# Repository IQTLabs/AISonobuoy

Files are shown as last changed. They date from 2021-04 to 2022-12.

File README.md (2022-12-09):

# AISonobuoy

Maritime Situational Awareness: An Exploration

# About

The AI Sonobuoy project is intended to demonstrate the process and design methodology for developing an AI-enabled hydrophone. We are building an integrated system that detects ship propellers using hydrophones. Data is collected, stored, and processed locally using onboard microprocessors. Onboard detection algorithms trigger remote alerts when objects of interest are detected.

# The Life Cycle of AI at the Edge Systems

## Sensor to Solution

Our Sensor to Solution methodology for this project involves a Collection system to record hydrophone audio, AIS data, and other environmental telemetry. An Analysis process automatically labels the audio data and trains a machine learning (ML) model. The ML model is then deployed on a low-power Detection device which can trigger remote alerts for detection events.

```mermaid 
graph LR
    A(Collection) --> B(Analysis) --> C(Detection)
```

Reference implementations for each of the Sensor to Solution functions can be seen below.

## Collection

### PiBuoy

A buoy designed to run an Raspberry Pi with power management that can do continuous collection of hydrophone audio. It is equipped with an AIS receiver and other sensors such as GPS, LTE, temperature, and a 9-axis gyroscope.

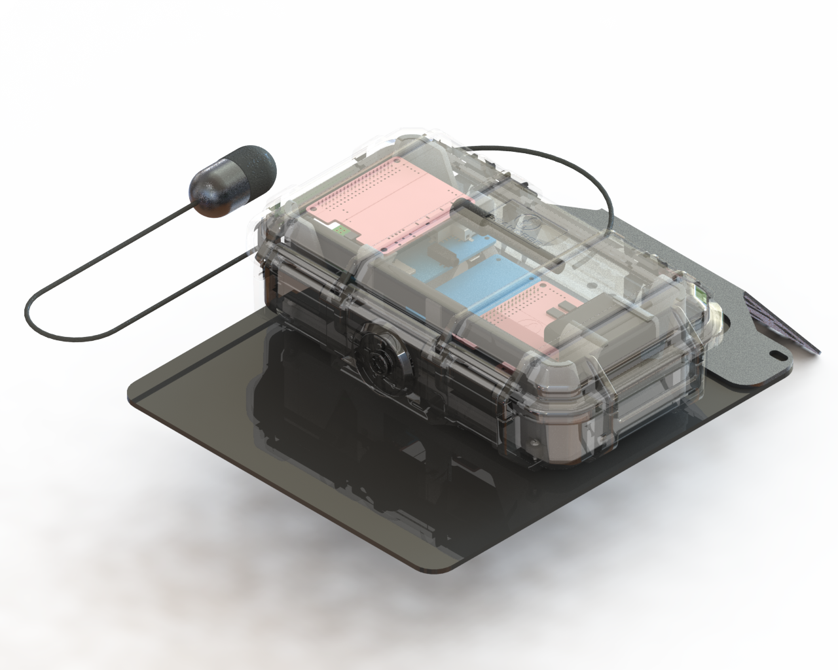
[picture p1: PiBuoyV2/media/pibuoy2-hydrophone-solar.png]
pibuoy


See [https://github.com/IQTLabs/aisonobuoy-collector-raspberrypi](https://github.com/IQTLabs/aisonobuoy-collector-raspberrypi)

## Analysis

### Manual Labeling

The simplest method for getting started with analysis is to manually label the audio data.  We use [Audacity](https://www.audacityteam.org) to label segments of boat/no\_boat in our audio files.

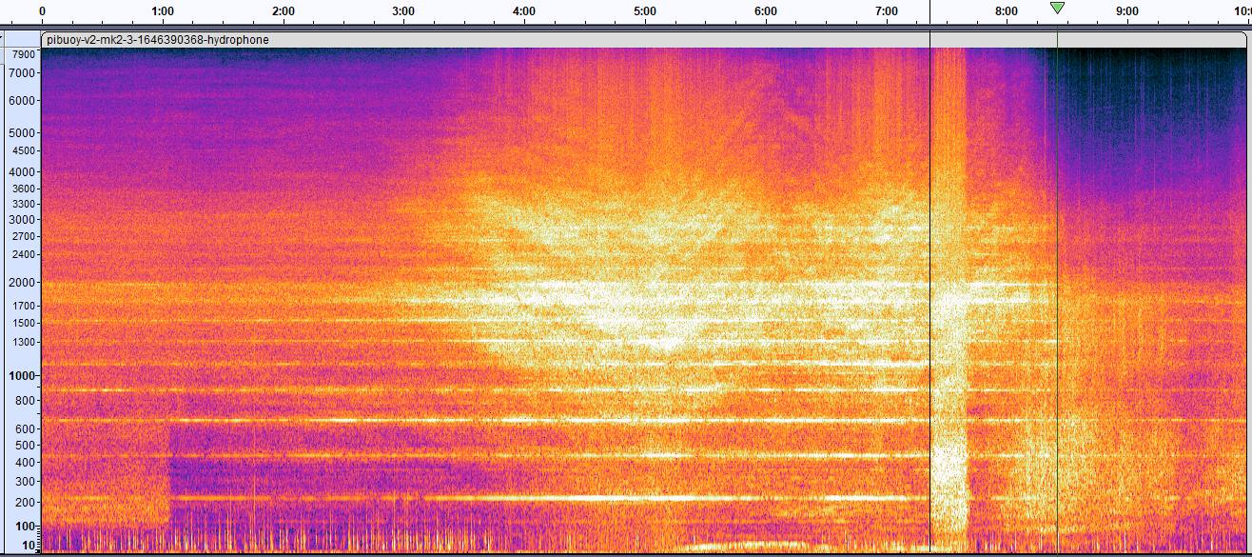
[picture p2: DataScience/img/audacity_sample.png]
pibuoy audacity


### Edge Impulse

With a set of labels in hand, we create a machine learning model using [Edge Impulse](https://www.edgeimpulse.com) that can easily be deployed to the edge.  We use spectrogram features to build a binary classifier for boat/no\_boat:

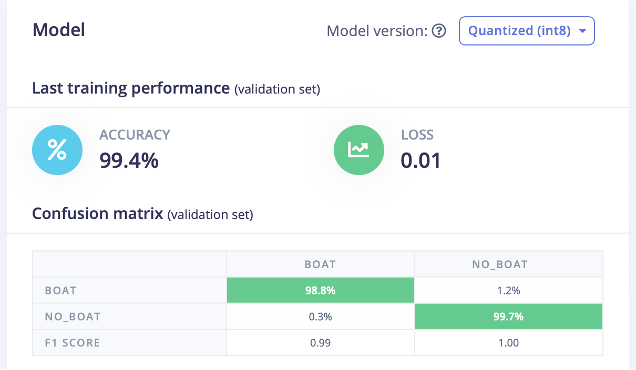
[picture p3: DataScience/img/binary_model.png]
pibuoy ei_model


### Bootstrapping Labels

For more sophisticated models, bootstrapping labels from the data collect is preferable to manual labeling.  We can use GPS tracks or [AIS](https://en.wikipedia.org/wiki/Automatic_identification_system) data to determine vessel speed and distance from the hydrophone.  This allows use to build a 5-class audio classifier with classes: no\_boat, near\_slow, near\_fast, far\_slow, far\_fast. Below we show the far\_slow portion of a particular test run.

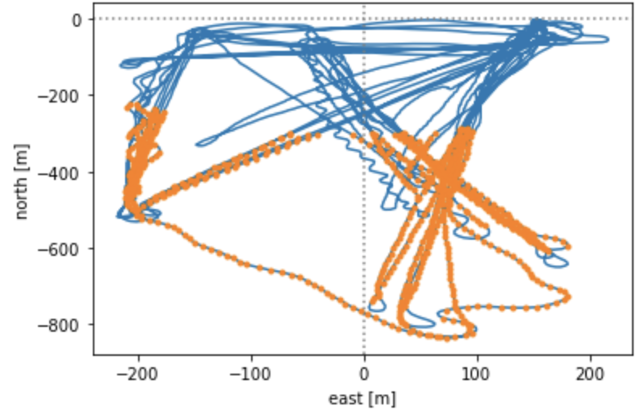
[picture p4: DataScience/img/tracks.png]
pibuoy tracks


Below we show the results of a 5-class Edge Impulse model.

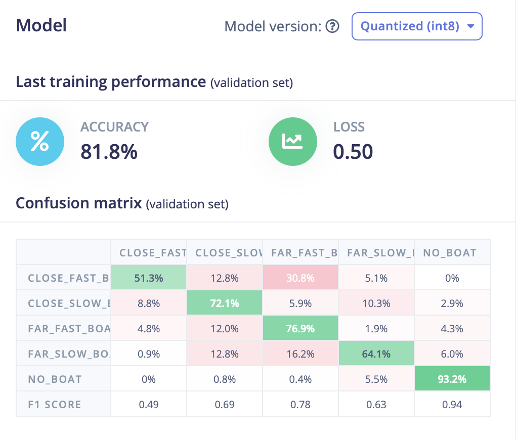
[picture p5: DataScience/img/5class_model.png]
pibuoy ei_model


See [DataScience](./DataScience/README.md) for further details.

## Detection

### ParticleTrackerBuoy

A buoy built around the [Particle.io Tracker SOM Evaluation Board](https://docs.particle.io/datasheets/asset-tracking/tracker-som-eval-board/). The Tracker Eval board is connected to a [Adafruit Quad 2x2 FeatherWing](https://www.adafruit.com/product/4253) via the i2c port to allow Feather form factor devices and sensors to be connected. An optional [Myriota Module](https://myriota.com/) can be used to enable satellite communications. The electronics are housed in a 4in schedule 40 PVC pipe. Ballast is added to the bottom of the pipe for appropriate floatation orientation. 

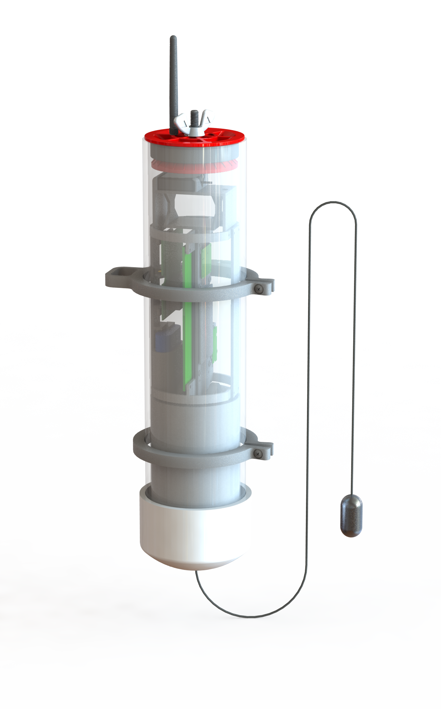
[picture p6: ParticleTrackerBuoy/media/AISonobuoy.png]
particle-tracker-buoy


See [ParticleTrackerBuoy/README](ParticleTrackerBuoy/README.md)

# Data Visualization

[Dashboards](https://alper.datav.is/assets/publications/dashboards/dashboards-preprint.pdf) and data visualizations are a key component of modern sensor collection systems, providing greater data visibility, transparency, and a common operating picture.

As part of the AI Sonobuoy project, we are developing a series of visualizations (shown below with locations masked) to help users with a wide range of real-time monitoring and operational decision-making tasks.

|Cloud IoT Visualizations|React Dashboard (Telemetry Data)|React Dashboard (Map View)|
|:--:|:--:|:--:|
|Thumbnail 1|Thumbnail 2|Thumbnail 3|

This visualization prototyping effort is a work-in-process focused on displaying the AI Sonobuoy's location, temperature (°F), humidity, and state of charge. However, future extensions might visualize different types of data and/or adopt different data encoding strategies. For more details, please see the `aisonobouy-react-dashboards` repository (currently internal-only).

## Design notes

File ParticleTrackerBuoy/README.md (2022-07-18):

# ParticleTrackerBuoy

## About

The Particle Tracker Buoy is an implementation of an Edge AI Detection device. It is intended to demonstrate the concept of an AI Sonobuoy. 



## Hardware

The Particle Tracker Buoy was designed to use low-cost and easily accessible components.

- Particle.io Tracker SOM
- Myriota Dev Kit
- Adafruit nRF52840 Sense MCU
- Adafruit Featherwing Quadrupler
- Adafruit Electret MAX4466 AMP
- Adafruit lithium ion 6600mAh battery
- 4in PVC pipe components
- 3D Printed chassis ([STL Files](stl-files))
- [Aquarian H2A Hydrophone](https://www.aquarianaudio.com/h2a-hydrophone.html)

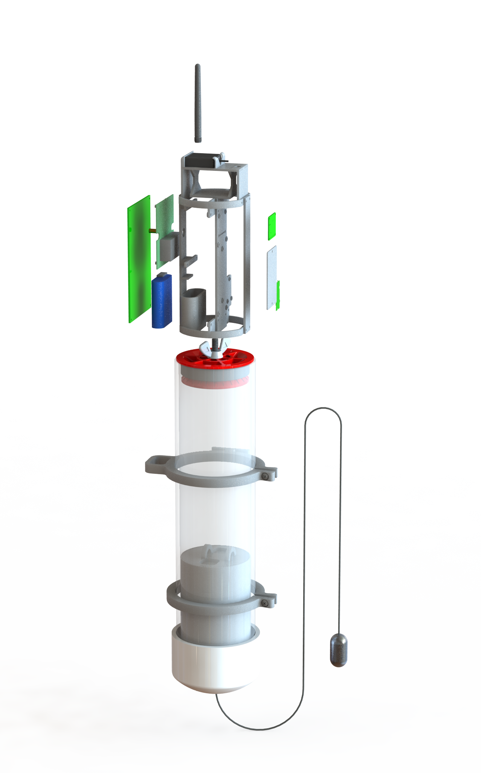
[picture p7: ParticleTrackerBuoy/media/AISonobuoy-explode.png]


[STL Files](stl-files)

## Wiring

```
┌───────────────┐     ┌────────────┐     ┌────────────┐     ┌───────────┐     ┌────────────┐
│   [SATCOM]    │     │[C&C /TELEM]│     │  [ML MCU]  │     │[AUDIO AMP]│     │[HYDROPHONE]│
│               │     │            │     │            │     │           │     │            │
│    Myriota    │     │  Particle  │     │  nRF52840  │     │  MAX4466  │     │  Aquarian  │
│      Dev      │     │  Tracker   │     │   Sense    │     │           │     │    H2A     │
│      Kit      │     │            │     │            │     │           │     │            │
│               │     │            │     │            │     │           │     │            │
│               │     │            │     │            │     │           │     │            │
│   26/LEUART TX├─────┤UART RX     │     │          A0├─────┤VCC        │     │            │
│   28/LEUART RX├─────┤UART TX     │     │          A1├─────┤OUT────────┼─────┤RED         │
│               │     │            │     │            │     │           │     │            │
│               │     │      A0/SDA├───┬─┤A4/SDA      │     │        MIC├─────┤GREEN       │
│               │     │            │   │ │            │     │           │     │            │
│               │     │      A1/SCL├─┬─┼─┤A5/SCL      │     │        GND├─────┤BLACK       │
│               │     │            │ │ │ │            │     │           │     │            │
│               │     │            │ │ │ │            │     │           │     │            │
│ VEXT          │     │            │ 1 1 │            │     │           │     │            │
│ /3.3      GND │     │ 3.3    GND │ 0 0 │ 3.3    GND │     │      GND  │     │            │
└──┬─────────┬──┘     └──┬──────┬──┘ k k └──┬──────┬──┘     └───────┬───┘     └────────────┘
   │         │           │      │    │ │    │      │                │
   │                     │           │ │    │
   └─────────────────────┴───────────┴─┴────┘
```

## Software

- The Particle Tracker firmware and flashing instructions are located in the [aisonobuoy-particle-tracker](https://github.com/IQTLabs/aisonobuoy-particle-tracker/) submodule.

- The Myriota Modem firmware and flashing instructions are located in the [modem-myriota](https://github.com/IQTLabs/modem-myriota) submodule

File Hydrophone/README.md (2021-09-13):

# TinyML & Hydrophones

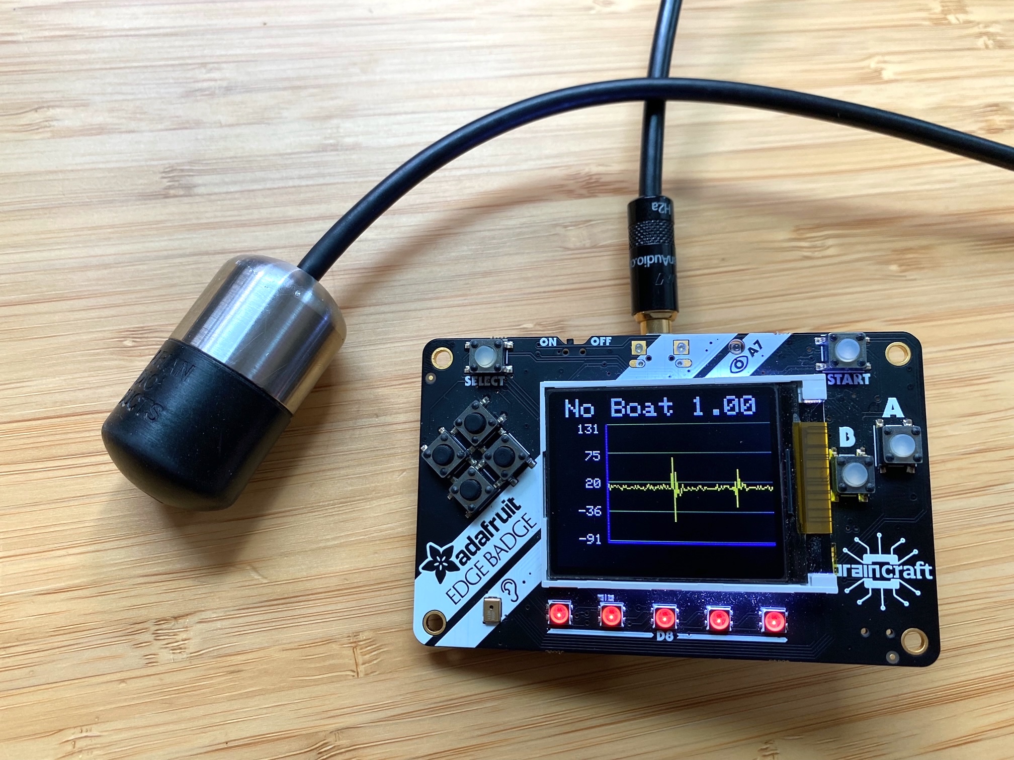
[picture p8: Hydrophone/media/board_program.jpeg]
board


## What are these things?

This is a small effort to look at running ML models against Hydrophone data on an Arduino or similar microcontroller. TinyML focuses on getting machine learning working on these lower power devices. New tools, like [Edge Impulse](https://www.edgeimpulse.com), have made it easy to start building your own ML models. 

Hydrophones are microphones that can capture underwater sounds. You will often see them in movies where they are hunting submarines. There are lots of interesting things you can hear underwater, like fish, volcanos and boats. 

Being able to push audio from a hydrophone through a TinyML model would make it possible to build a self-contained sensor that could detect underwater events.

## What is this?

This work was put together to see if it is possible to detect underwater events on an Arduino. It includes a board for connecting a hydrophone to a microntroller and a small Arduino program that runs an ML model and displays whether a boat was detected.

### Hydrophone Interface Board

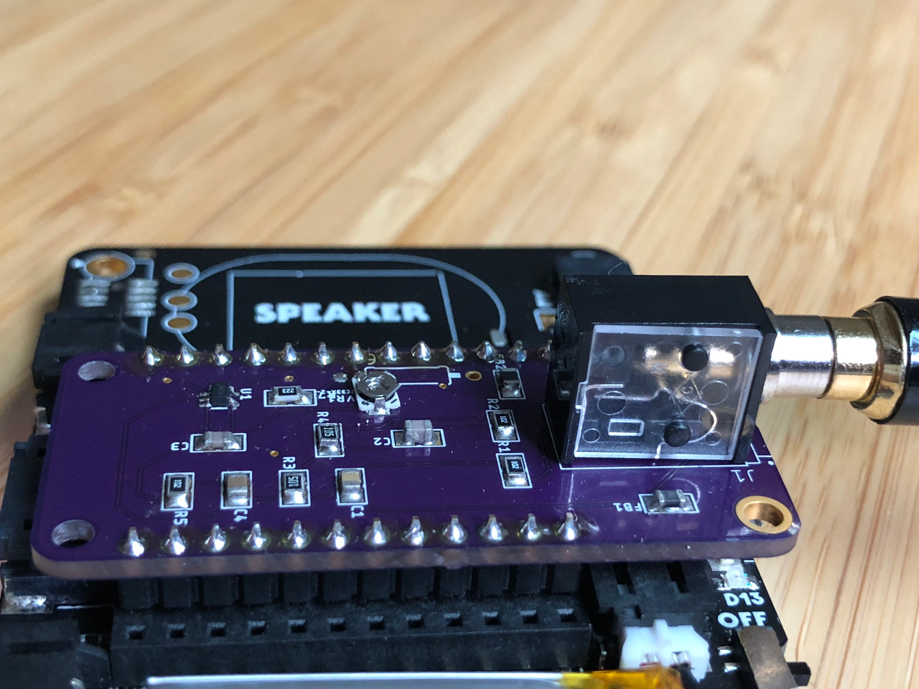
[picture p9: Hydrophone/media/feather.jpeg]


This is a Featherwing form factor board that has a 3.5mm jack, a MAX4466 chip and adjustable gain. It outputs the amplified audio out on one of the Feather analog pinouts. There is a short step-by-step walk through on how I built the board on [Hackster.io](https://www.hackster.io/robotastic/hydrophone-feather-board-03f1d7).

I used the following parts. I am not an EE, so feel free to pick more appropriate components (and send me a PR if you do!):
- [Adafruit PyBadge](https://www.adafruit.com/product/4200)
- [Capacitor 0.01uF / 10000pF 0805](https://www.digikey.com/en/products/detail/CL21C103JBFNNNG/1276-6487-1-ND/5958115?itemSeq=376128529)
- [Capacitor 10uF 0805](https://www.digikey.com/short/m8wb1vc5)
- [Capacitor 100pF 0805](https://www.digikey.com/short/bvph8r4p)
- [Capacitor 0.1uF 0805](https://www.digikey.com/short/ftrt382h)
- [Ferrite Bead 0805](https://www.digikey.com/short/7c5j278m)
- [3.5mm Monojack](https://www.digikey.com/short/59mz8349)
- [Resistor 1k ohm 0805](https://www.digikey.com/short/q990d7bq)
- [Resistor 1M ohm 0805](https://www.digikey.com/short/53rz9h3m)
- [Resistor 22K ohm 0805](https://www.digikey.com/short/hj1djmt8)
- [MAX4466EXK+T  SC-70-5](https://www.digikey.com/short/vnww7j39)
- [Featherwing Male Headers](https://www.adafruit.com/product/3002) 

Here is a short journey on how the board came to be:

I selected the Aquarian hydrophone to work with. The [H2A model](https://www.aquarianaudio.com/h2a-hydrophone.html) seemed to be rugged and reasonably priced, for a hydrophone. It uses a standard 3.5mm jack, making it easy to connect to a lot of different recorders. 

I haven't worked much with microphones before, so I learned a number of things. First, microphones need a bit of power to work, so they will not work on a "line-in" input. For interfacing with an Arduino, this means that you can not simply hook it up to a GPIO pin and read the signal. You need to put some power through the microphone. Secondly, the actual signal from a microphone is quite faints and needs to be amplified before you can start to work with. 

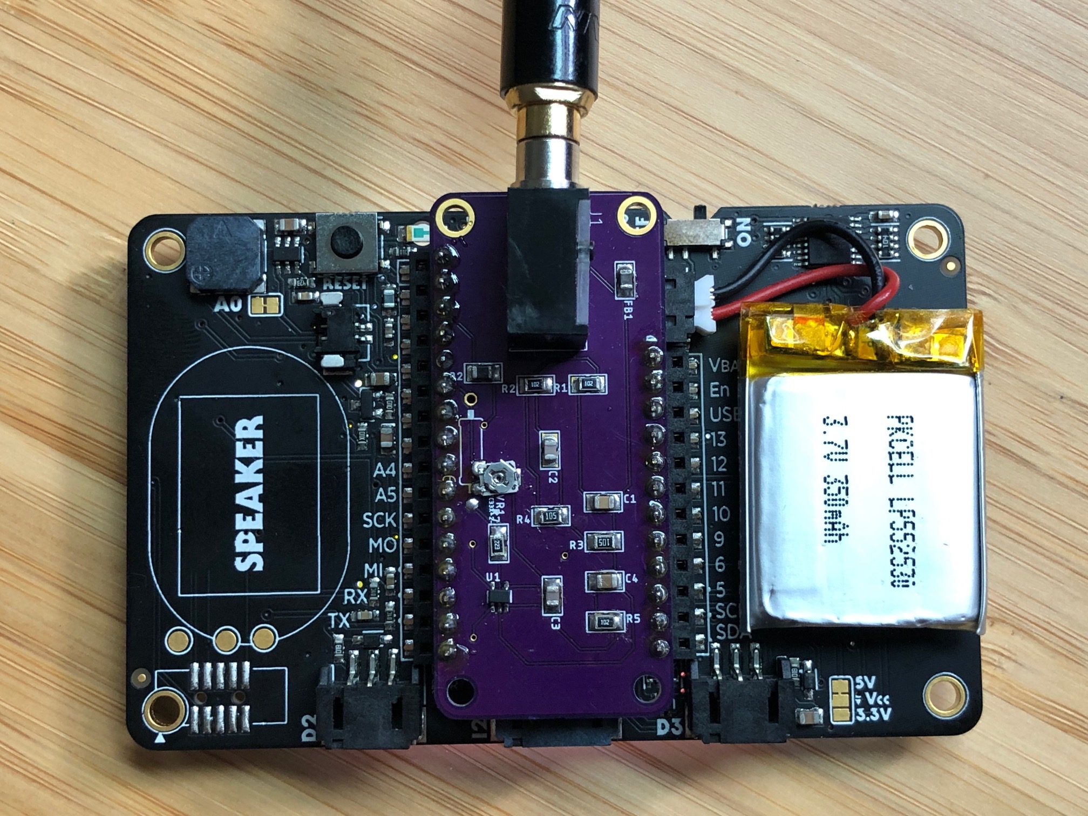
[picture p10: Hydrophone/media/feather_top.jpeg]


The good news is that there are lots of existing chips for working with microphones that handle both the power and the gain. The surprising thing though, was that I couldn't find an existing board that had a 3.5mm jack and was designed to be connected to an Arduino. In fact, there wasn't really that much information about recording analog audio, directly from a microphone using Arduino. Most of the microphone breakout boards I found were for MEMS style microphones and most of them put out a digital signal. 

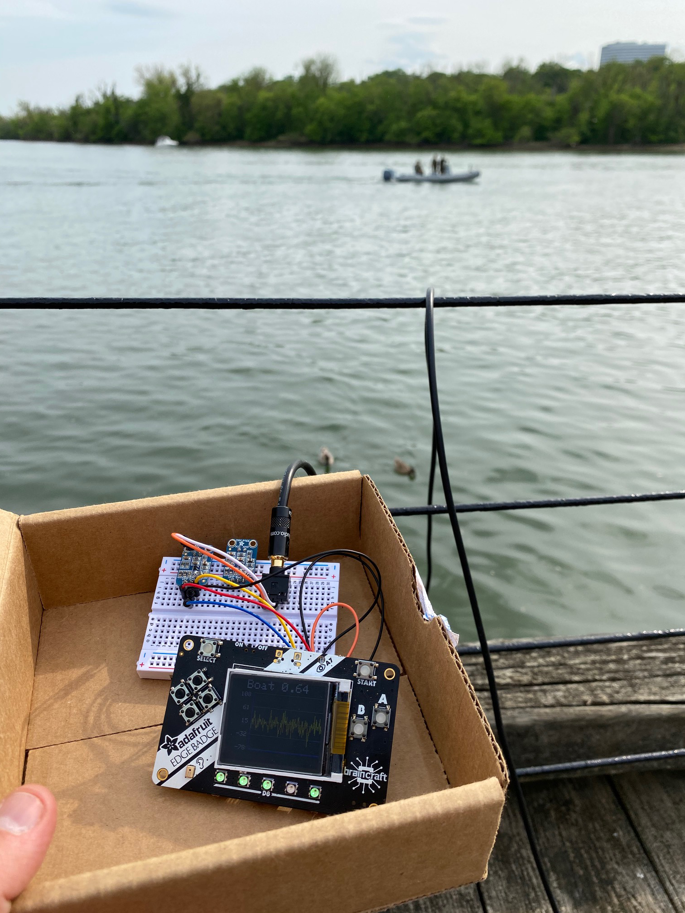
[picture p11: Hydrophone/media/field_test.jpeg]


Adafruit does have a nice [breakout board](https://www.adafruit.com/product/1063) that uses a MAX4466 chip to power and amplify a Electret  Microphone. This is a similar type of microphone as the one inside the hydrophone. Adafruit also published a nice [guide](https://learn.adafruit.com/tensorflow-lite-for-edgebadge-kit-quickstart/assembly) on how to connect this microphone to one of their [dev boards](https://www.adafruit.com/product/4200) and how to run a TinyML model against that audio. Sampling the audio is a bit of a brute force approach - you simply set an interrupt and sample the pin at a set interval. As a quick experiment, I removed the microphone from the breakout board, added a 3.5mm jack and was able to record audio from the hydrophone.

One of the great things about Adafruit is that they open source all of their hardware designs. I started with the design files for the Electret Mic Breakout Board, moved them around to fit inside the feather form factor and added a 3.5mm jack.

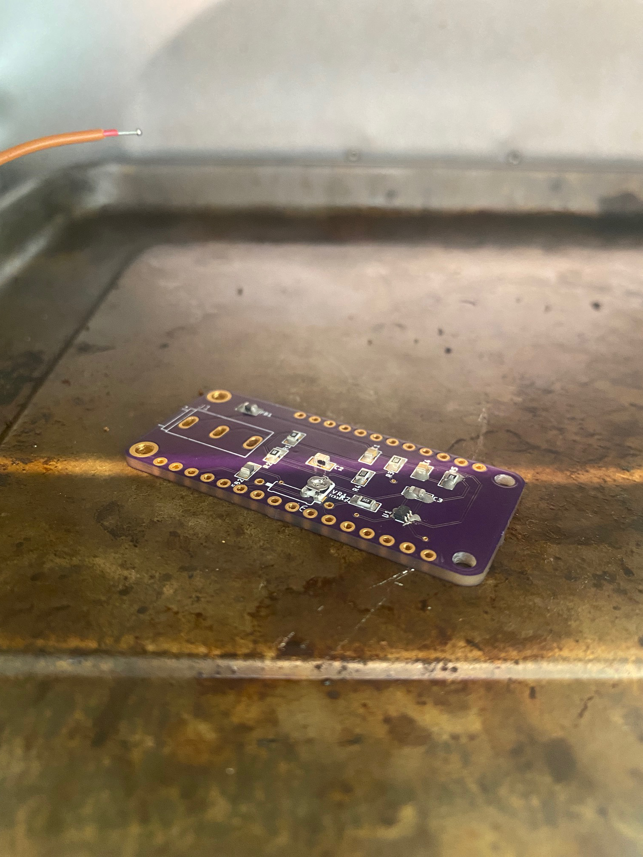
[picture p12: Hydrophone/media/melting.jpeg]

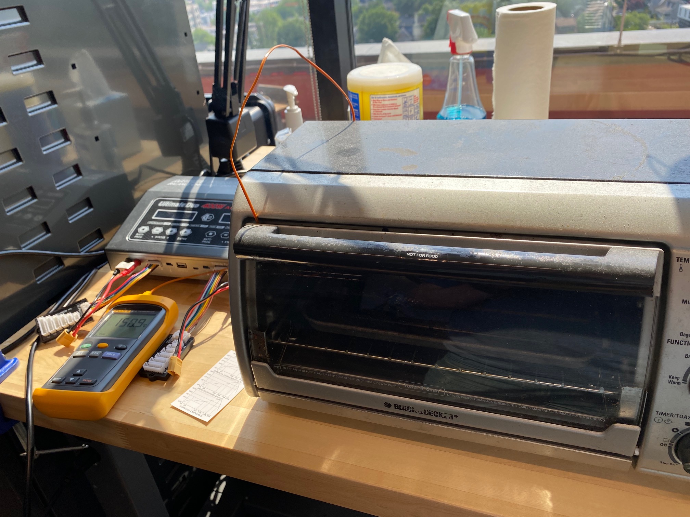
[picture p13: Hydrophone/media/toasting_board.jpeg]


The resulting board fits nicely on the back of the PyBadge and will work with the large range of dev boards that are in the Feather form factor.

Unfortunately, the audio from the interface board is not as high quality as audio recorded from a digital recorder (Zoom H1n). In order to evaluate performance I used an underwater speaker to playback an audio clip. I placed both the microphone and hydrophone in bucket, to try and make it a little more realistic. 

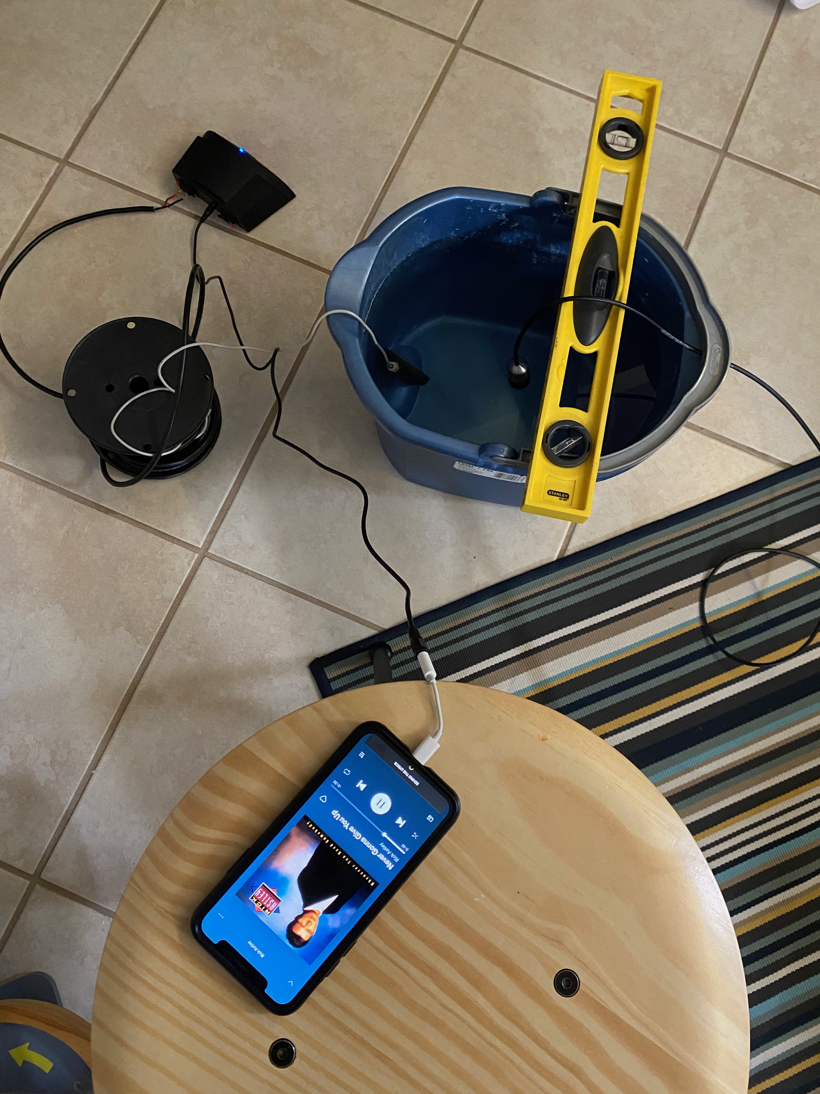
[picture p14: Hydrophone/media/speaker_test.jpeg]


- [Interface Board](media/FeatherWing-Audio-Test.wav)
- [Digital Recorder](media/Digital-Recorder.wav)

As you can hear, the audio recorded by the interface board is a little more muffled and has more noise than the audio recorded by the digital recorder. (It is a little jumpy because it is recorded in 1 second segments.)

The difference maybe from the sampling technique used to capture the audio, it is only 12-bits. It is more likely from the design of the interface board. Cleaning amplifying audio is an art... and I am not an artist. Any improvements to the design of the interface board would be greatly appreciated.

### Arduino Program

The Arduino program builds off of the example Arduino program from Edge Impulse for inferencing. It is designed to run on the Adafruit [Pybadge](https://www.adafruit.com/product/4200) or Edge Badge. These are a series of development boards with a SAMD51 Cortex M4F processor and a small TFT LCD screen. 

The example program is written to pull audio from a PDM microphone. I updated it to instead sample from an analog pin. The results of running the model on the audio are displayed on the screen, along with the waveform of the audio. It makes for a compact kit for debugging and evaluating model performance in the field.

## Building an ML Based Boat Detector

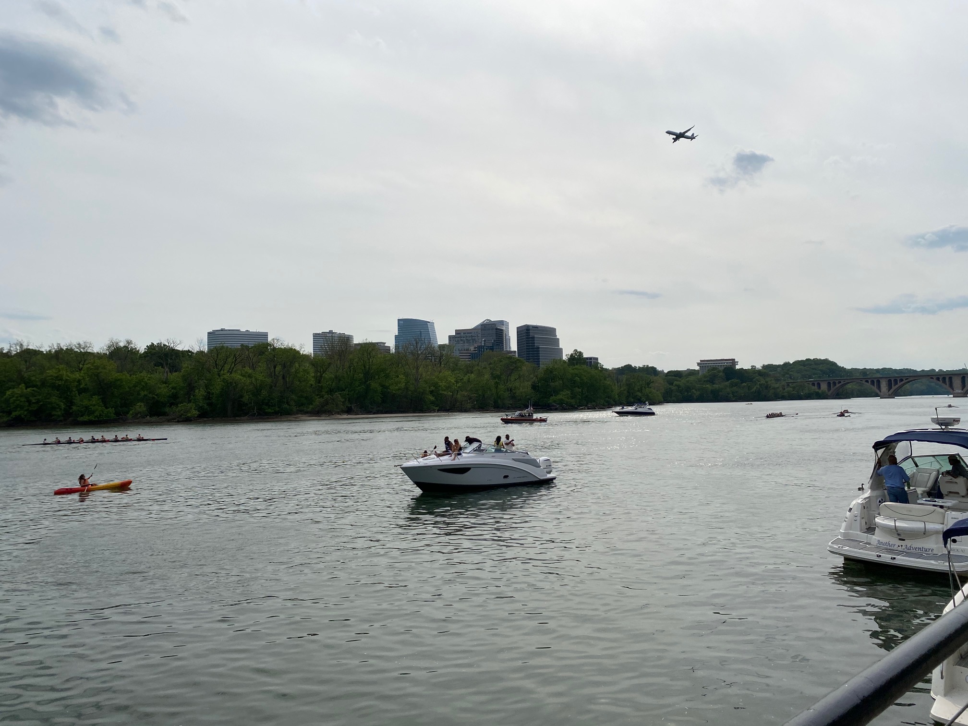
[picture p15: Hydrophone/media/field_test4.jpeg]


Generally, the first step in building an ML model is to collect data and label it. For boat detection, I wanted recordings where there was a boat going by in the water and also recordings where there are no boats present. I captured the recordings using a [Zoom H1n recorder](https://zoomcorp.com/en/us/handheld-recorders/handheld-recorders/h1n-handy-recorder/) and the Acquarian hydrophone. In addition to not being an audio expert, I am also not a boating expert. I learned a couple lessons about boats by trying to make these recordings:

1. Just because a boat is docked and not moving, doesn't mean that it is making boat sounds. It turns out that a pump and maybe a motor will be running even if the boat is docked. This means that it is a bad idea to try and record near a marina, because there will be a lot of background boat sounds, even if nothing is moving nearby.
1. Boats can sound very different. The diesel engine on the water taxi sounds a lot different that the outboard engine on a power boat.

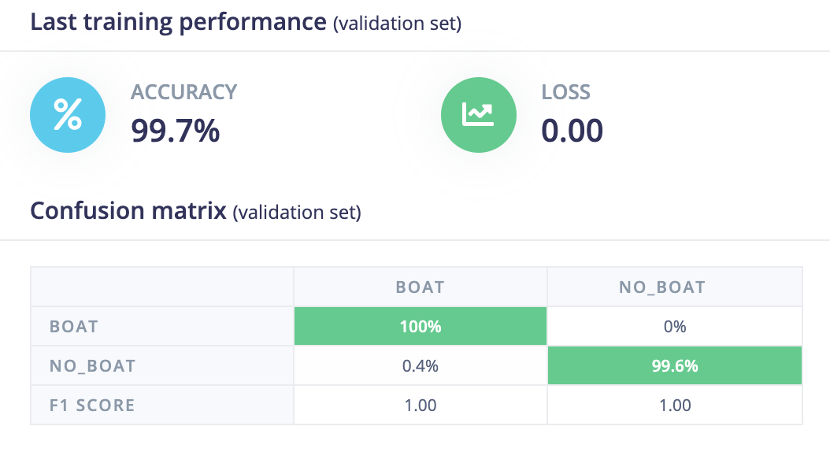
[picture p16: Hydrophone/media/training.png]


I uploaded the different recordings to Edge Impulse and trained a model. They have recently added an AutoML feature to the platform and using that I was able to train a model that almost perfectly classified each type of audio. This is encouraging, but also suggests that I may need more audio and more variety.

## Results 
I did some field evaluation and the system is able to detect nearby boats. More testing is need to see how it would perform in different bodies of water besides a river. Additional training data should help improve performance and allow the model to generalize to a broader range of boats and conditions. Improvements to the interface board should also improve performance.

An Arduino library that includes this model is included. I will look to added the recorded audio to the repo in the future.

## Contact

If you have questions or advice, please reach out to me (Luke Berndt) -> lberndt@iqt.org

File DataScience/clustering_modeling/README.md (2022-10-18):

# Clustering + Plotting Pipeline for Hydrophone Audio Data

This pipeline creates 1-Dimensional audio features and then clusters them via k-Means clustering and plots a dimensionality reduced UMAP with ground truth and prediced class labels. An example can be seen below. 

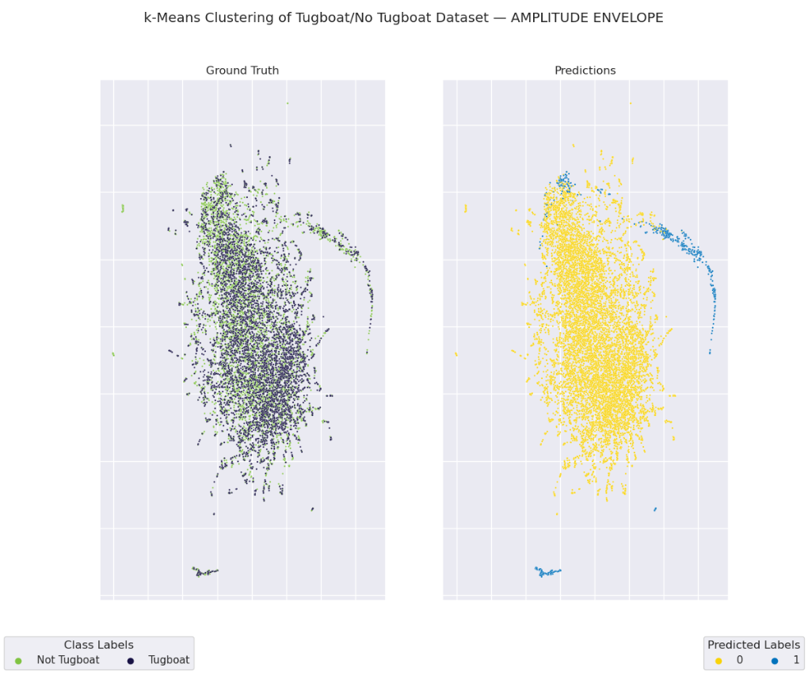
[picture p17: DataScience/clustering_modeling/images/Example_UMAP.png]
UMAP


The overall pipeline can be seen below. 

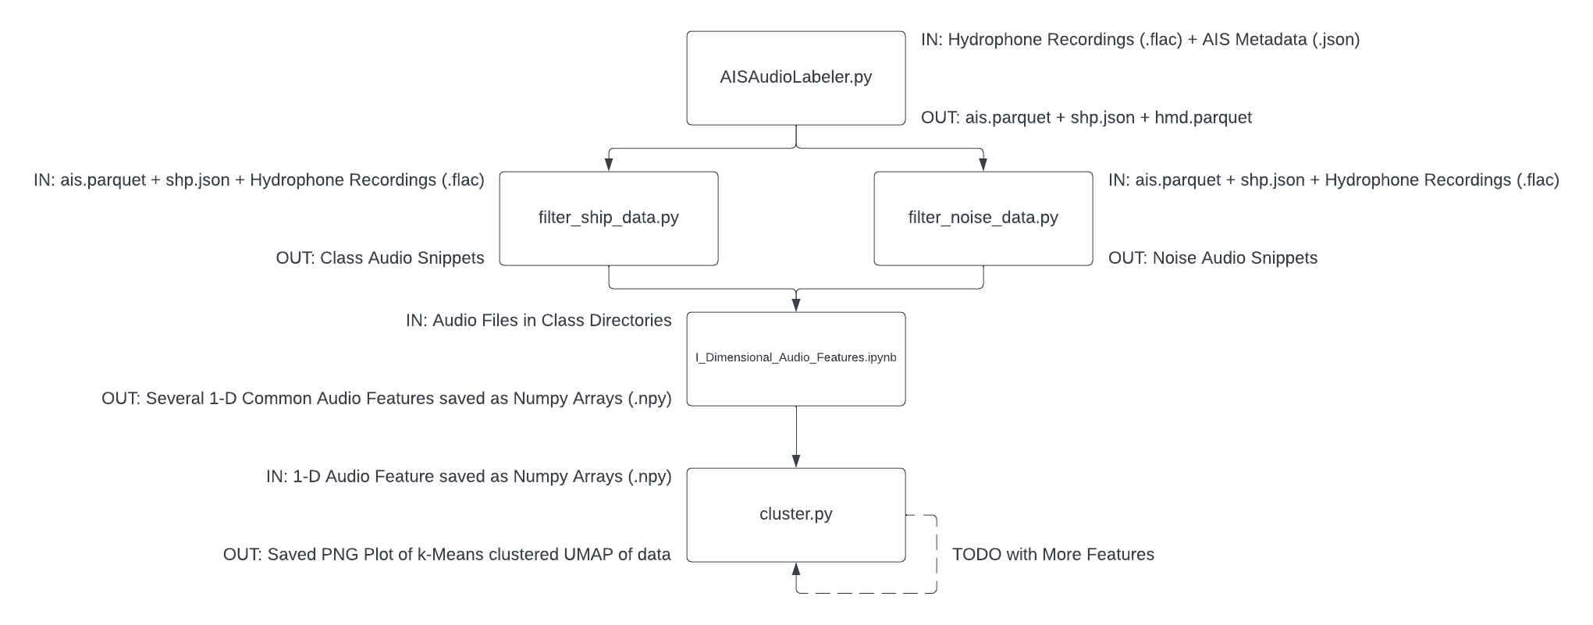
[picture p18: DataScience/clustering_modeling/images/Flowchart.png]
Flowchart


**Note:** This pipeline leverages NVIDIA's `cuML` library as part of their [RAPIDS](https://rapids.ai/index.html) GPU accelerated modeling library, but will still run if you do not have it installed. To run with `cuML`, we reccomend using the Docker option from [here](https://rapids.ai/start.html#get-rapids).

To download (you may have to configure for your enviornment): 

```
docker pull nvcr.io/nvidia/rapidsai/rapidsai-core:22.08-cuda11.5-runtime-ubuntu20.04-py3.8
```

Run the command below from the working directory (`$PWD`) that you want to expose to the docker container where your data is saved (again, you may have to configure for your enviornment).

```
docker run --gpus all --rm -it --shm-size=1g --ulimit memlock=-1 -p 8888:8888 -p 8787:8787 -p 8786:8786 --mount type=bind,source="$(pwd)",target=/rapids/notebooks/host nvcr.io/nvidia/rapidsai/rapidsai-core:22.08-cuda11.5-runtime-ubuntu20.04-py3.8
```

If running on `ssh` in a separate terminal on the host machine you would like to port-forward your `jupyter-lab` session to, run: 

```
ssh -i <PATH_TO_KEYFILE> <HOST_ACCOUNT> -NL 8888:localhost:8888
```

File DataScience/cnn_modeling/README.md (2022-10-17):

# AI SONOBUOY MODELING PIPELINE

**This pipeline is currently under devlopment**

Currently the AISonobuoy Modeling Pipeline takes data collected by the AISonobuoy and trains a ResNet-18 model binary classifier to discriminate between "Tug" boats and everything else. 

The pipeline can be seen below. 

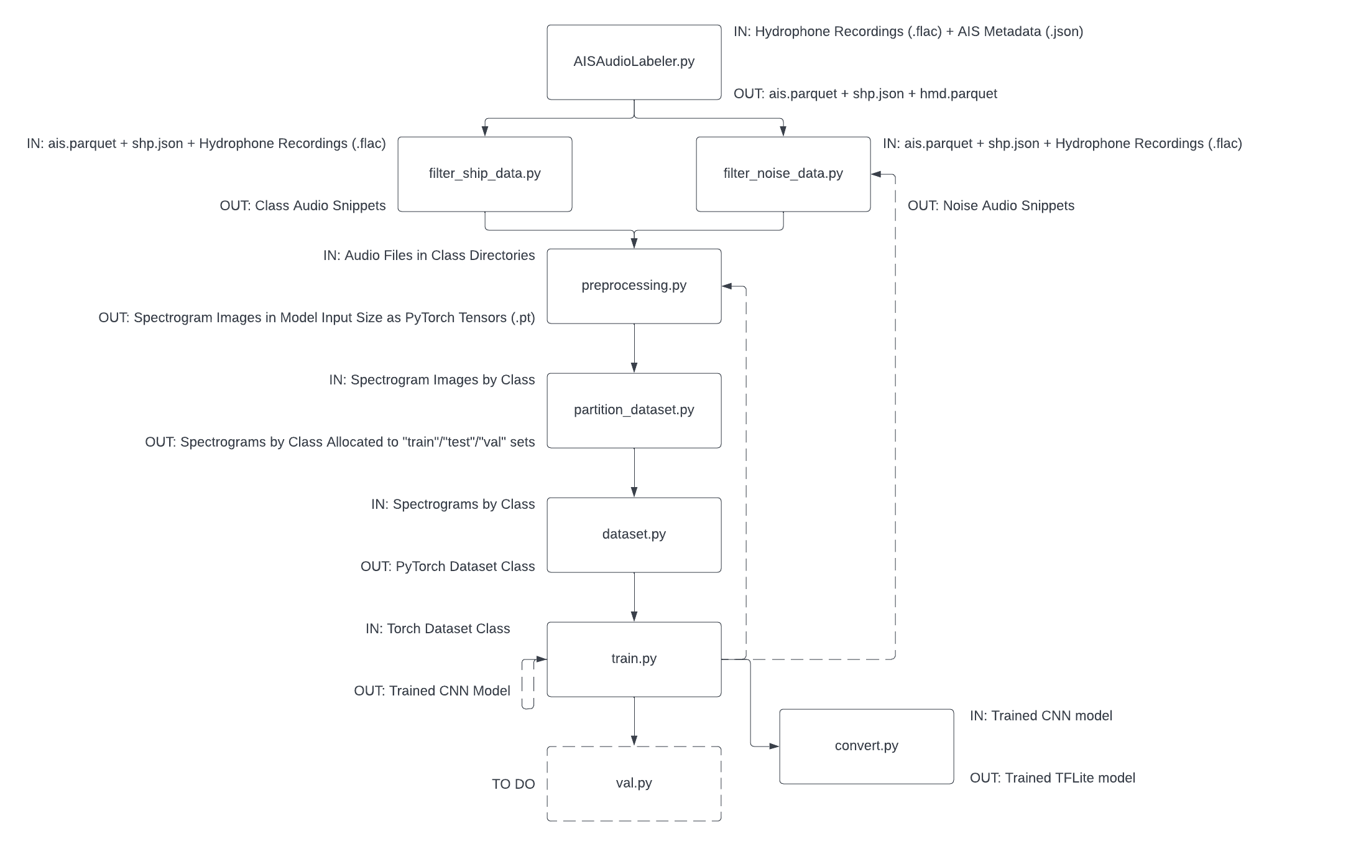
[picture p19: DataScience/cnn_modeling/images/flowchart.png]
flowchart


- `filter_ship_data.py`: Isolates hydrophone audio segments for the class of interest (currently `Tug`) and saves them under a class-label directory 
- `filter_noise_data.py`: Isolates hydrophone audio segments w/ a naive heuristic for filtering out boat noise and saves them under a class-label directory
- `preprocessing.py`: Loads audio segments from the previous step and converts them to an STFT-based spectrogram image PyTorch tensors (of size [3,224,224] which is the ResNet input size) and saves them in class-labelled directories 
- `partition_dataset.py`: Partitions the tensors from the previous step into a `training`, `test`, and `val` sets for training/evaluation and saves as separate set directories w/ class-labelled sub-directories. 
- `dataset.py`: Creates a PyTorch dataset class and creates image-label pairings to be used in training 
- `train.py`: A PyTorch training loop that takes a model (currently ResNet-18) and uses the image-label data pairings to make predictions + learn from them
- `convert.py`: Takes the trained PyTorch model and converts it to an ONNX model, Keras model, and then a TFLite model for use on the edge

---

To visualize model training with Tensorboard run: `tensorboard --logdir=<PATH_TO_TENSORBOARD_LOG_DIR>`. The `logdir` by default is `runs`.

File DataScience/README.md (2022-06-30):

# DataScience

The DataScience directory contains Python modules and Jupyter
Notebooks for creating labeled audio files from simultaneous audio
recordings and GPS or AIS data collections.

The GpxAudioLabeler module provides methods and a command-line
interface for the processing of the audio and GPS data collected in a
controlled environment with specified audio sources. The
AisAudioLabeler module provides methods and a command-line interface
for the processing of the audio and AIS data collected by
pibuoy-v2. The LabelerUtilites module provides methods for coordinate
transformations, clustering, and plotting, and the S3Utilities.py
module provides simplified and documented methods for interacting with
AWS S3.

## GpxAudioLabeler

The GpxAudioLabeler module provides methods and a command-line
interface for:
* Parsing a GPX file produced with a specified structure
* Exporting audio clips by heading, heading first derivative,
  distance, and speed clusters or limits
* Plot source track and label the intersection of the heading, heading
  first derivative, distance, and speed groups

The command line interface has the following usage and optional
arguments:

    Usage: GpxAudioLabeler.py [-h] [-D DATA_HOME] [-c COLLECTION_FILENAME] [-s SAMPLING_FILEPATH] [-C CLIP_HOME]
                              [-p] [-P]

    Optional arguments:
      -h, --help            Show this help message and exit
      -D DATA_HOME, --data-home DATA_HOME
                            The directory containing all GPX, WAV, and JSON files
      -c COLLECTION_FILENAME, --collection-filename COLLECTION_FILENAME
                            The path of the collection JSON file to load
      -s SAMPLING_FILEPATH, --sampling-filepath SAMPLING_FILEPATH
                            The path of the sampling JSON file to process
      -C CLIP_HOME, --clip-home CLIP_HOME
                            The directory containing clip WAV files
      -p, --do-plot-clips   Do plot track with identified clips
      -P, --do-plot-metrics
                            Do plot track with computed metrics

### Collection JSON

The collection JSON contains information in the following format to
describe the sources and hydrophones used during the collection.

Start and stop times are in seconds from the beginning of the
collection. Geodetic latitude, and longitude are in degrees. Elevation
is in meters.

Format:

    {
        "sources": [
            {
                "type": "file" | "bucket"
                "name": "track.gpx",
                "start_t": 0,
                "stop_t": 8000.0
            }
        ],
        "hydrophones": [
            {
                "type": "file",
                "name": "unit.wav",
                "lat": 0.0,
                "lon": 0.0,
                "ele": 0.0,
                "start_t": 1000,
                "stop_t": 9000
            }
        ]
    }

### Sample JSON

The sample JSON document contains entries in the following format
which describe the method, and its parameters, used in creating
labeled samples from the collection. The method can be either
"clusters" or "conditionals".

If "clusters", the samples are all placed in the specified output
directory, and labeled with the start and stop times, and the
distance, heading, heading rate, and speed cluster averages.

If "conditionals", the samples are all placed in the output directory
and labeled with the start and stop times, and the distance, heading,
heading rate, and speed limits. Multiple entries with the
"conditionals" method will result in samples in a set of labeled
directories.

The maximum time delta between positions used to define a contiguous
audio sample is in seconds.

Format:

    [
        {
            "name": "default",
            "method": {
                "type": "clusters",
                "distance_n_clusters": 3,
                "heading_n_clusters": 10,
                "heading_dot_n_clusters": 2,
                "speed_n_clusters": 4
            },
            "delta_t_max": 4.0,
            "n_clips_max": 3,
            "output_dir": "default"
        },
        {
            "name": "close-north-stable-fast",
            "method": {
                "type": "conditionals",
                "distance_limits": [0, 250],
                "heading_limits": [-10, 0, 0, 10],
                "heading_dot_limits": [0, 1],
                "speed_limits": [10, 20]
            },
            "delta_t_max": 4.0,
            "n_clips_max": 3,
            "output_dir": "close-north-stable-fast"
        }
    ]

Where:
* `delta_t_max` specifies the maximum time delta between positions in
  seconds used to define a contiguous audio sample
* `n_clips_max` specifies the maximum number of clips exported in each
  segment

## AisAudioLabeler

The AisAudioLabeler module provides methods and a command-line
interface for:
* Downloading, validating, and decompressing all objects, optionally
  identified by their prefix, in an AWS S3 bucket to a local path
* Loading all AIS files
* Probing all audio files using ffprobe
* Augmenting AIS data with distance from the hydrophone, speed, and
  ship counts when underway, or not underway
* Exporting audio clips from AIS intervals during which a specified
  maximum number of ships at a specified maximum distance are
  reporting their status as underway, and labeling the audio clip
  using the attributes of the ship closest to the hydrophone
* Uploading all audio clips found on the upload path to a bucket with
  a prefix
* Plotting ship status and hydrophone recording intervals
* Plotting histogram of distance for times at which at most a
  specified maximum number of ships are reporting their status as
  underway

The [Automatic Identification System
(AIS)](https://www.navcen.uscg.gov/automatic-identification-system-overview)
is a ship-to-ship collision avoidance system that allows for
communication of position, speed, and other ship data via a VHF
virtual data link (VDL) network. Mariners worldwide use AIS to ensure
safety at sea.

[AIS message reporting
requirements](https://www.navcen.uscg.gov/ais-requirements) depend on
to which of two vessel classes, A and B, a vessel belongs. Class A
vessels meet at least one of the following requirements:
* A self-propelled vessel of 65 feet or more in length, engaged in
  commercial service
* A towing vessel of 26 feet or more in length and more than 600
  horsepower, engaged in commercial service
* A self-propelled vessel that is certificated to carry more than 150
  passengers
* A self-propelled vessel engaged in dredging operations in or near a
  commercial channel or shipping fairway
* A self-propelled vessel engaged in the movement of –
  + Certain dangerous cargo, or
  + Flammable or combustible liquid cargo in bulk

Class B vessels meet at least one of the following requirements:
* Fishing industry vessels
* Vessels certificated to carry less than 150 passengers and that–
  + Do not operate in a Vessel Traffic Service (VTS) or Vessel
  Movement Reporting System (VMRS) area
  + Do not operate at speeds in excess of 14 knots
* Vessels engaged in dredging operations not in or near a commercial
  channel or shipping fairway

AIS messages include [position and static
data](https://www.navcen.uscg.gov/ais-messages) reports. The
AisAudioLabeler module processes Class A position [Message IDs 1, 2,
and 3](https://www.navcen.uscg.gov/ais-class-a-reports) and static
data [Message ID
5](https://www.navcen.uscg.gov/ais-class-a-static-voyage-message-5)
reports, and Class B position and static data [Message ID 18, and
24](https://www.navcen.uscg.gov/ais-class-b-reports) reports.

The command line interface has the following usage and optional
arguments:

    Usage: AisAudioLabeler.py [-h] [-D DATA_HOME] [-c COLLECTION_FILENAME] [-s SAMPLING_FILEPATH] [-C CLIP_HOME]
                              [-d] [--force-download] [--force-ais-parquet] [--force-hmd-parquet] [--force-shp-json]
                              [--export-clips] [--upload-audio-clips] [--plot-intervals] [--plot-histogram]

    Optional arguments:
      -h, --help            Show this help message and exit
      -D DATA_HOME, --data-home DATA_HOME
                            The directory containing all downloaded AIS files
      -c COLLECTION_FILENAME, --collection-filename COLLECTION_FILENAME
                            The path of the collection JSON file to load
      -s SAMPLING_FILEPATH, --sampling-filepath SAMPLING_FILEPATH
                            The path of the sampling JSON file to process
      -C CLIP_HOME, --clip-home CLIP_HOME
                            The directory containing clip WAV files
      -d, --decompress      Decompress downloaded files
      --force-download      Force file download
      --force-ais-parquet   Force AIS parquet creation
      --force-hmd-parquet   Force hydrophone metadata parquet creation
      --force-shp-json      Force SHP JSON creation
      --export-clips        Do export audio clips
      --upload-audio-clips  Do upload audio clips
      --plot-intervals      Do plot ship status and hydrophone recording intervals
      --plot-histogram      Do plot ship distance from hydrophone histogram

### Collection JSON

The collection JSON contains information in the following format to
describe the sources and hydrophones used during the collection.

Geodetic latitude, and longitude are in degrees. Elevation is in
meters.

Format:

    {
        "sources": [
            {
                "type": "bucket",
                "name": "aisonobuoy-pibuoy-v2",
                "prefix": "compressed",
                "label": "v2-mk2-3"
            }
        ],
        "hydrophones": [
            {
                "type": "bucket",
                "name": "aisonobuoy-pibuoy-v2",
                "prefix": "compressed",
                "label": "v2-mk2-3",
                "lat": 0.0,
                "lon": 0.0,
                "ele": 0.0
            }
        ]
    }

### Sample JSON

The sample JSON document contains entries in the following format
which describe the method, and its parameters, used in creating
labeled samples from the collection.

The maximum distance is in meters.

Format:

    [
        {
            "name": "default",
            "max_n_ships": 3,
            "max_distance": 500.0,
            "output_dir": "no-more-than-three-or-500-m-then-min-distance"
        }
    ]

Where:
* `max_n_ships` specifies the maximum number of ships underway
  simultaneously
* `max_distance` specifies the maximum distance of ships underway
  simultaneously from the hydrophone

## LabelerUtilites

The LabelerUtilites module provides methods for:
* Computing the geocentric position given geodetic longitude and
  latitude, and elevation
* Computing geocentric east, north, and zenith unit vectors at a given
  geodetic longitude and latitude, and the corresponding orthogonal
  transformation matrix from geocentric to topocentric coordinates
* Computing the topocentric position and velocity of the source
  relative to the hydrophone, and corresponding heading, heading first
  derivative, distance, and speed
* Computing clusters of distance, heading, heading first derivative,
  and speed
* Plotting source track, and histograms of source distance, heading,
  heading first derivative, and speed

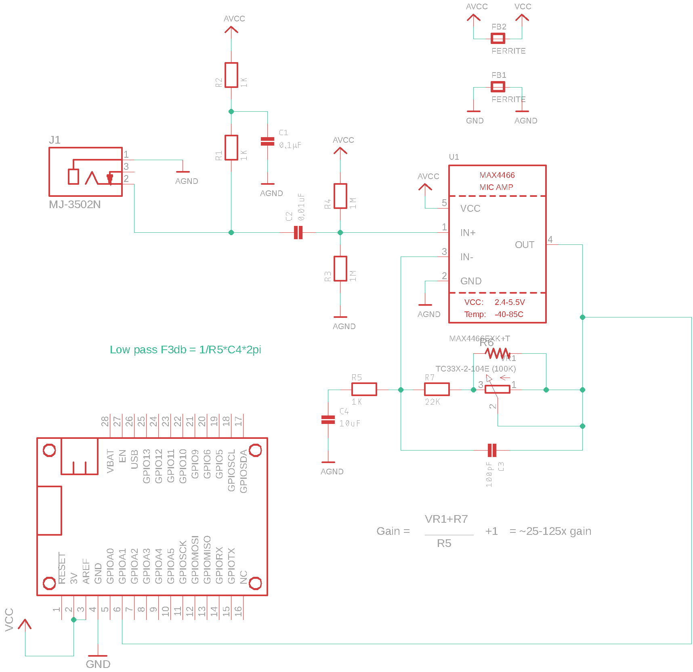
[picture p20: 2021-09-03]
Hydrophone/Featherwing Interface/v1.2 - Fabbed/schematic-v1.2.png

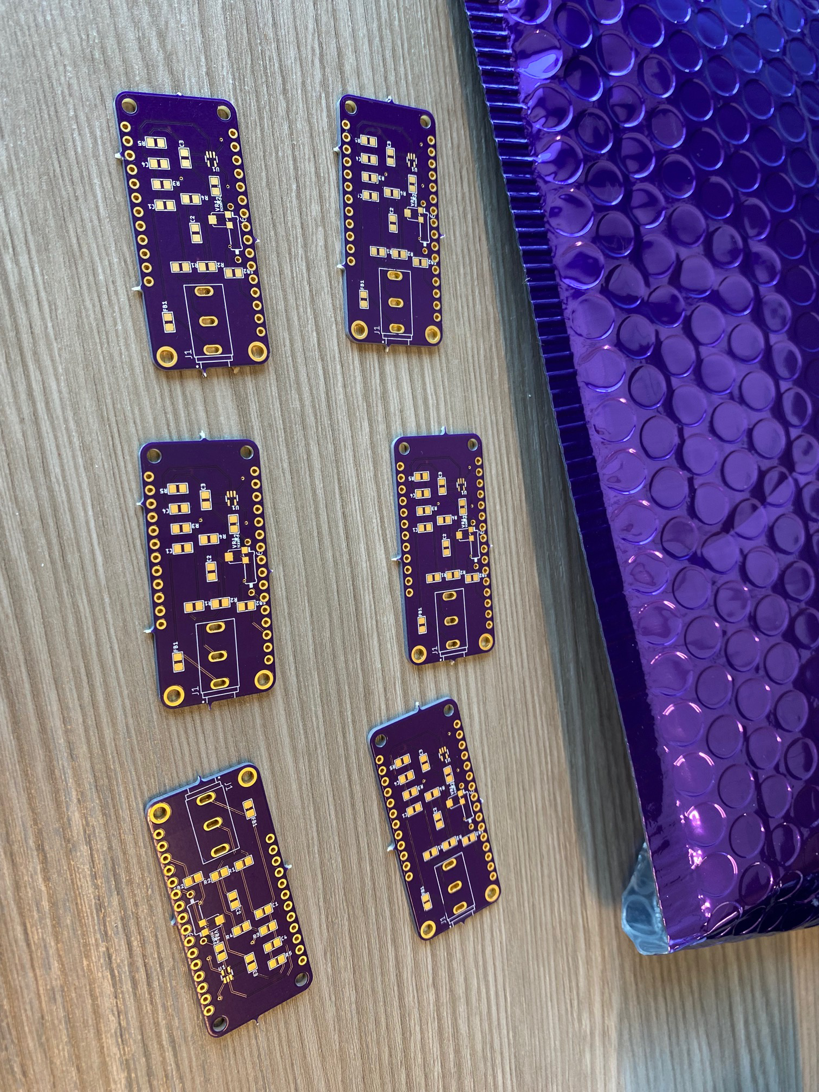
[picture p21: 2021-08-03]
Hydrophone/media/raw_board.jpeg

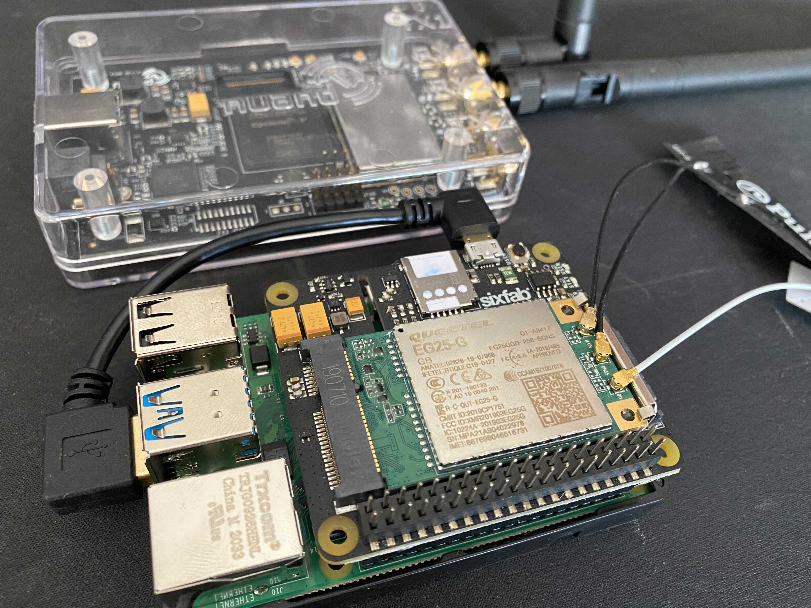
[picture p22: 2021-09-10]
docs/img/sixfab_bladerf.jpg

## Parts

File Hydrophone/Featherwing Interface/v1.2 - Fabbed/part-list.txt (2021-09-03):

Partlist

Exported from featherwing-interface.brd at 9/3/21 9:34 AM

EAGLE Version 9.6.2 Copyright (c) 1988-2020 Autodesk, Inc.

Assembly variant: 

Part     Value               Package                Library      Position (mil)        Orientation

C1       0.1µF               0805                   microbuilder (1350 2100)           R90
C2       0.01uF              0805                   microbuilder (1150 1900)           R0
C3       100pF               0805                   microbuilder (1700 1900)           R0
C4       10uF                0805                   microbuilder (1650 2100)           R90
FB1      FERRITE             0805                   microbuilder (500 2200)            R0
FB2      FERRITE             0805                   microbuilder (850 1650)            R270
J1       MJ-3502N            CUI_MJ-3502N           MJ-3502N     (500 1900)            R0
MS1      FEATHERWING         FEATHERWING            adafruit     (150 1450)            R0
R1       1K                  0805                   microbuilder (900 2050)            R270
R2       1K                  0805                   microbuilder (900 1850)            R270
R3       1M                  0805                   microbuilder (1500 2100)           R270
R4       1M                  0805                   microbuilder (1400 1900)           R270
R5       1K                  0805                   microbuilder (1800 2100)           R90
R6                           0207/10                rcl          (1150 1600)           R180
R7       22K                 0805                   microbuilder (1500 1700)           R180
U1       MAX4466EXK+T        SC70-5                 microbuilder (1700 1700)           R90
VR1      TC33X-2-104E (100K) TRIMPOT_BOURNS_TC33X-2 microbuilder (1250 1700)           R0

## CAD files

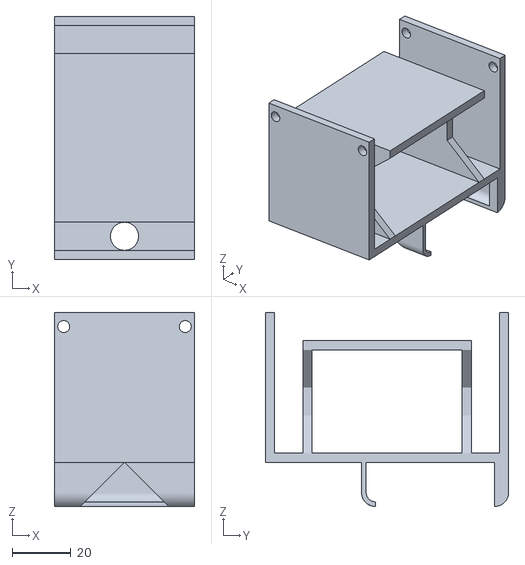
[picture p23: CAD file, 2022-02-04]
ParticleTrackerBuoy/stl-files/4in PVC Particle Tracker Buoy - 3D Printed Electronics Payload Chassis GPS Mount^4in PVC Particle Tracker Buoy-1.STL
47.6 x 82.5 x 65.8

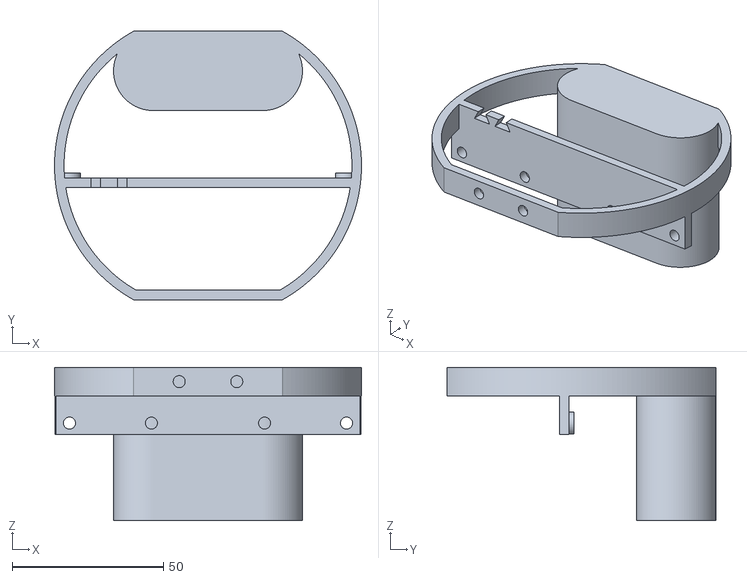
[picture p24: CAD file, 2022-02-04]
ParticleTrackerBuoy/stl-files/4in PVC Particle Tracker Buoy - 3D Printed Electronics Payload Chassis End^4in PVC Particle Tracker Buoy-1.STL
101.6 x 88.9 x 50.8

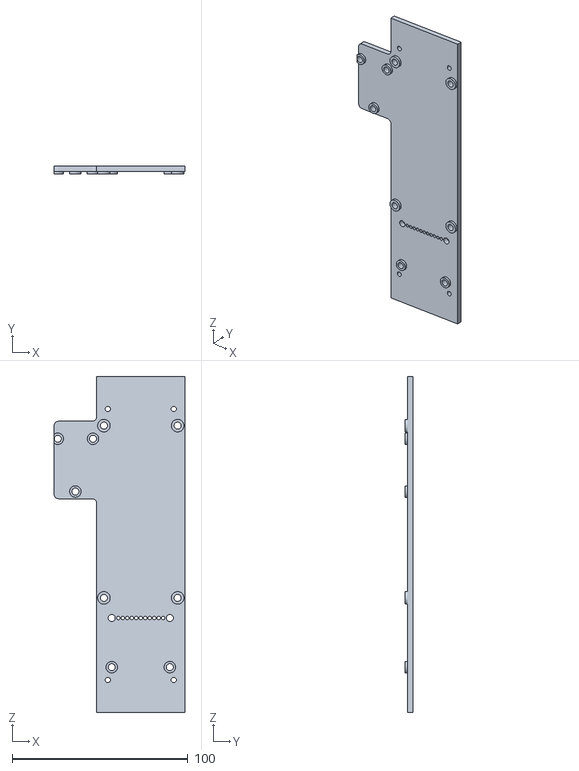
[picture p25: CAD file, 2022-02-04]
ParticleTrackerBuoy/stl-files/4in PVC Particle Tracker Buoy - 3D Printed Electronics Payload Chassis Center Panel^4in PVC Particle Tracker Buoy-1.STL
74.4 x 4.76 x 191.0

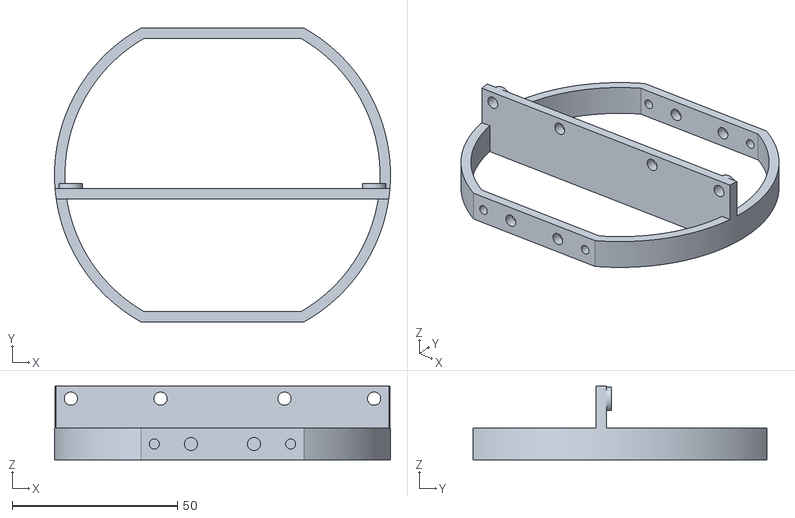
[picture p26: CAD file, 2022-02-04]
ParticleTrackerBuoy/stl-files/4in PVC Particle Tracker Buoy - 3D Printed Electronics Payload Chassis End^4in PVC Particle Tracker Buoy-2.STL
101.6 x 88.9 x 22.2

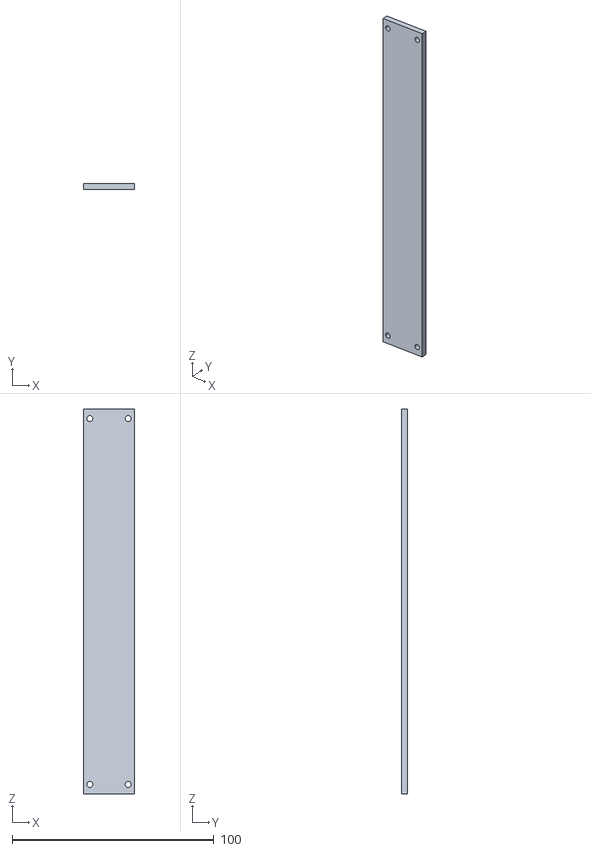
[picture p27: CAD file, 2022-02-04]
ParticleTrackerBuoy/stl-files/4in PVC Particle Tracker Buoy - 3D Printed Electronics Payload Chassis Side Support^4in PVC Particle Tracker Buoy-2.STL
25.4 x 3.17 x 191.0

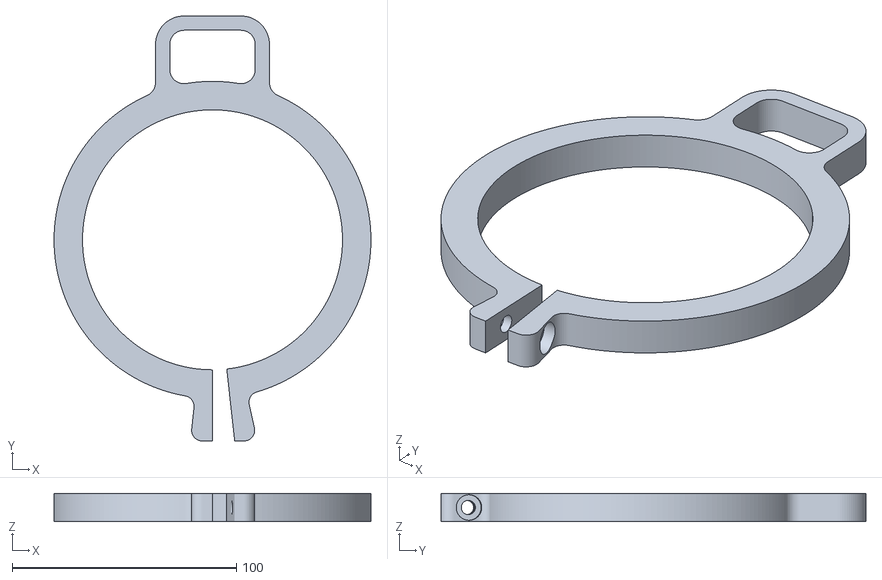
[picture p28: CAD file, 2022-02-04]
ParticleTrackerBuoy/stl-files/4in PVC Particle Tracker Buoy - Tether Strap^4in PVC Particle Tracker Buoy-1 3D Printed Tether Strap-1.STL
141.3 x 189.5 x 12.7

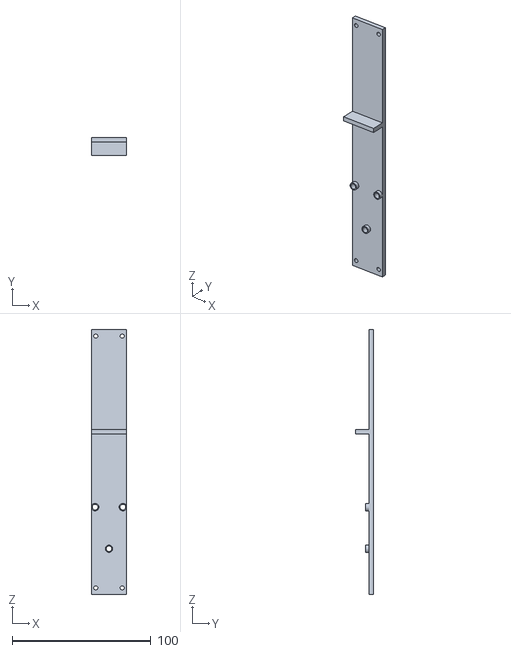
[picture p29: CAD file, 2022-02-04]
ParticleTrackerBuoy/stl-files/4in PVC Particle Tracker Buoy - 3D Printed Electronics Payload Chassis Side Support^4in PVC Particle Tracker Buoy-1.STL
25.4 x 12.7 x 191.0

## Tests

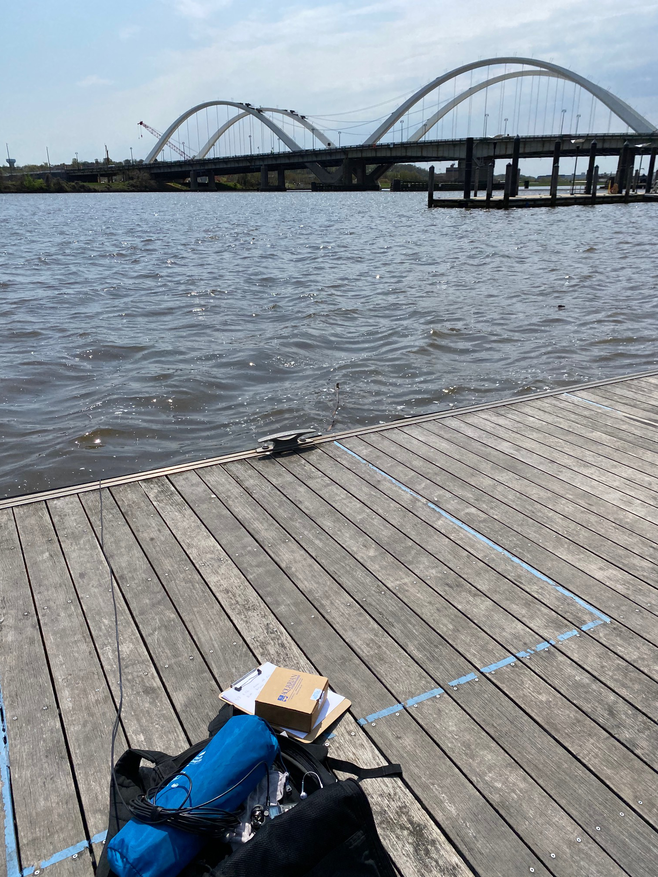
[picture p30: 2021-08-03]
Hydrophone/media/field_test3.jpeg

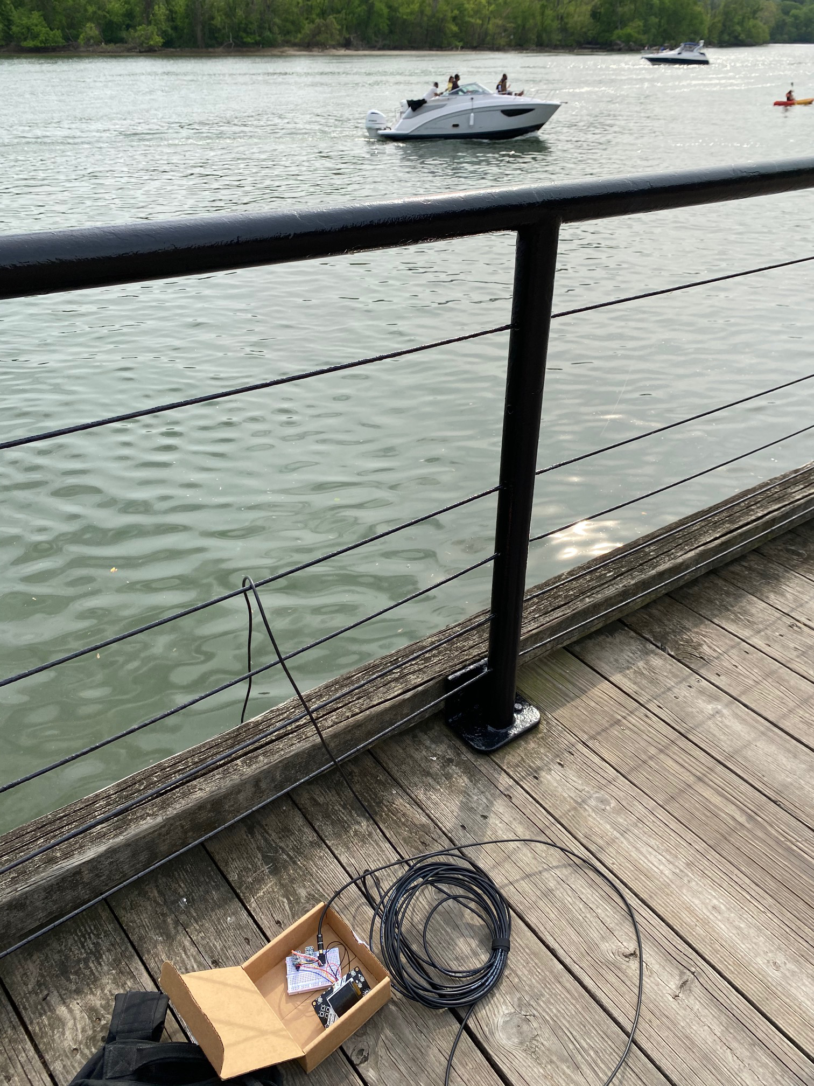
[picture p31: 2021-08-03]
Hydrophone/media/field_test2.jpeg

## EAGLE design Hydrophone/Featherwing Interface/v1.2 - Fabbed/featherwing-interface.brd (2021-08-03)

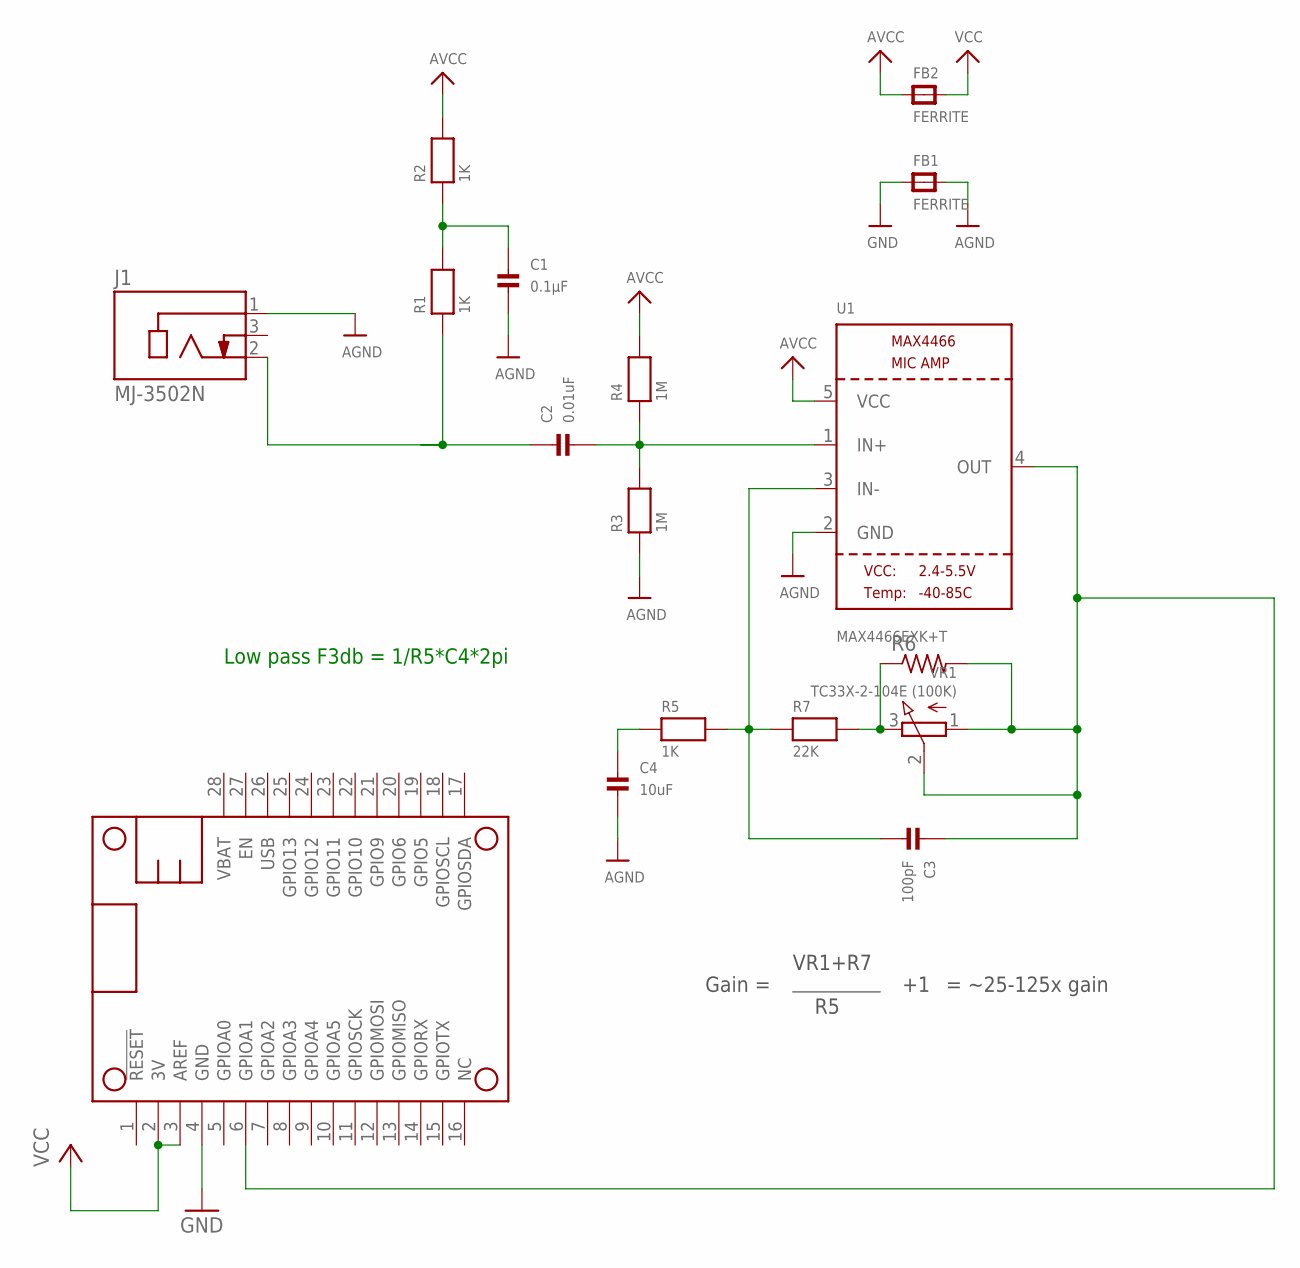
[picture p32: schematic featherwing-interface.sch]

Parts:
C1: 0.1µF; 0805
C2: 0.01uF; 0805
C3: 100pF; 0805
C4: 10uF; 0805
FB1, FB2: FERRITE; 0805
J1: MJ-3502N; CUI_MJ-3502N
MS1: FEATHERWING
R1, R2, R5: 1K; 0805
R3, R4: 1M; 0805
R6: R-US_0207/10; 0207/10
R7: 22K; 0805
U1: MAX4466EXK+T; SC70-5
VR1: TC33X-2-104E (100K); TRIMPOT_BOURNS_TC33X-2

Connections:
AGND: C1.2, C4.2, FB1.2, J1.1, R3.1, U1.2 (GND)
AVCC: FB2.1, R2.2, R4.2, U1.5 (VCC)
GND: FB1.1, MS1.4 (GND)
unnamed: C3.2, R5.2, R7.1, U1.3 (IN-)
unnamed: R6.1, R7.2, VR1.3 (E)
unnamed: C2.1, J1.2, R1.1
unnamed: C1.1, R1.2, R2.1
unnamed: C2.2, R3.2, R4.1, U1.1 (IN+)
unnamed: C3.1, MS1.6 (GPIOA1), R6.2, U1.4 (OUT), VR1.1 (A), VR1.2 (S)
unnamed: C4.1, R5.1
VCC: FB2.2, MS1.2 (3V), MS1.3 (AREF)

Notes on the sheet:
Gain =
VR1+R7
= ~25-125x gain
Low pass F3db = 1/R5*C4*2pi

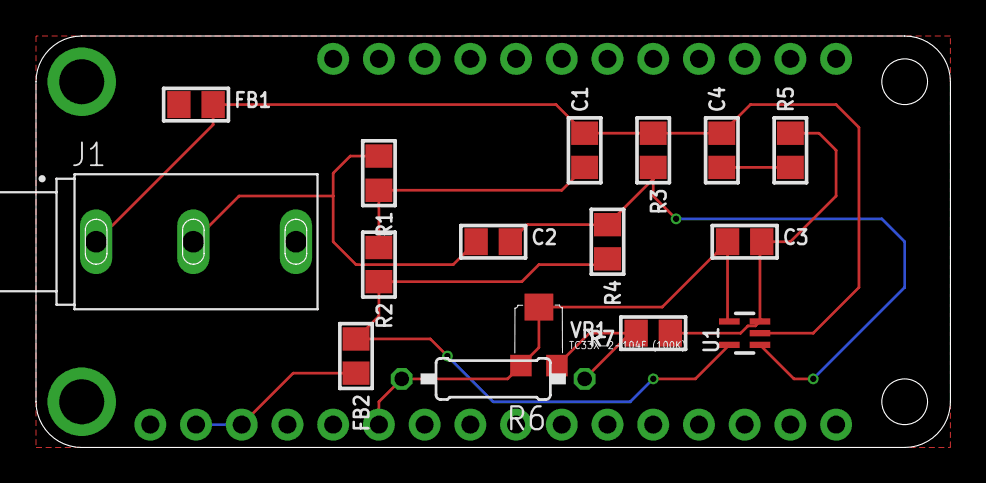
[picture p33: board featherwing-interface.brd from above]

Board: 2 copper layers, 50.8 x 22.9 mm, 17 parts (0 on the bottom side), 11 nets.

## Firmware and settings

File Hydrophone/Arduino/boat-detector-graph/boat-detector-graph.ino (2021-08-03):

/* Edge Impulse Arduino examples
 * Copyright (c) 2021 EdgeImpulse Inc.
 *
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
 * THE SOFTWARE IS PROVIDED "AS IS", WITHOUT WARRANTY OF ANY KIND, EXPRESS OR
 * IMPLIED, INCLUDING BUT NOT LIMITED TO THE WARRANTIES OF MERCHANTABILITY,
 * FITNESS FOR A PARTICULAR PURPOSE AND NONINFRINGEMENT. IN NO EVENT SHALL THE
 * AUTHORS OR COPYRIGHT HOLDERS BE LIABLE FOR ANY CLAIM, DAMAGES OR OTHER
 * LIABILITY, WHETHER IN AN ACTION OF CONTRACT, TORT OR OTHERWISE, ARISING FROM,
 * OUT OF OR IN CONNECTION WITH THE SOFTWARE OR THE USE OR OTHER DEALINGS IN THE
 * SOFTWARE.
 */

// If your target is limited in memory remove this macro to save 10K RAM
#define EIDSP_QUANTIZE_FILTERBANK   0
#define USE_EXTERNAL_MIC A1
//#define AUDIO_OUT A0     
/* Includes ---------------------------------------------------------------- */

#include <boat-detector_inferencing.h>
#include <Adafruit_Arcada.h>
#include <CircularBuffer.h>
#include <Math.h>

// Color definitions
#define BACKGROUND_COLOR __builtin_bswap16(ARCADA_BLACK)
#define BORDER_COLOR __builtin_bswap16(ARCADA_BLUE)
#define PLOT_COLOR_1 __builtin_bswap16(ARCADA_YELLOW)
#define TITLE_COLOR __builtin_bswap16(ARCADA_WHITE)
#define TICKTEXT_COLOR __builtin_bswap16(ARCADA_WHITE)
#define TICKLINE_COLOR __builtin_bswap16(ARCADA_DARKGREY)

// Buffers surrounding the plot area
#define PLOT_TOPBUFFER 20
#define PLOT_LEFTBUFFER 40
#define PLOT_BOTTOMBUFFER 20
#define PLOT_W (ARCADA_TFT_WIDTH - PLOT_LEFTBUFFER)
#define PLOT_H (ARCADA_TFT_HEIGHT - PLOT_BOTTOMBUFFER - PLOT_TOPBUFFER)

// Which pin to plot
#define ANALOG_INPUT A1

// Buffer for our plot data
CircularBuffer<float, PLOT_W> data_buffer;

/** Audio buffers, pointers and selectors */
typedef struct {
    int16_t *buffer;
    uint8_t buf_ready;
    uint32_t buf_count;
    uint32_t n_samples;
} inference_t;

static inference_t inference;
static signed short sampleBuffer[2048];
static bool debug_nn = false; // Set this to true to see e.g. features generated from the raw signal
static char graph_title[100];


Adafruit_Arcada arcada;


/**
 * @brief      Arduino setup function
 */
void setup()
{
    // put your setup code here, to run once:
    Serial.begin(115200);

    Serial.println("Edge Impulse Inferencing Demo");

    // summary of inferencing settings (from model_metadata.h)
    ei_printf("Inferencing settings:\n");
    ei_printf("\tInterval: %.2f ms.\n", (float)EI_CLASSIFIER_INTERVAL_MS);
    ei_printf("\tFrame size: %d\n", EI_CLASSIFIER_DSP_INPUT_FRAME_SIZE);
    ei_printf("\tSample length: %d ms.\n", EI_CLASSIFIER_RAW_SAMPLE_COUNT / 16);
    ei_printf("\tNo. of classes: %d\n", sizeof(ei_classifier_inferencing_categories) / sizeof(ei_classifier_inferencing_categories[0]));

    if (microphone_inference_start(EI_CLASSIFIER_RAW_SAMPLE_COUNT) == false) {
        ei_printf("ERR: Failed to setup audio sampling\r\n");
        return;
    }
      // Hook up the callback that will be called with each sample
  #if defined(USE_EXTERNAL_MIC)
    arcada.timerCallback(EI_CLASSIFIER_FREQUENCY, TIMER_CALLBACK);
    analogReadResolution(12);
  #endif
  #if defined(AUDIO_OUT) 
  pinMode(AUDIO_OUT, OUTPUT);
  analogWriteResolution(12);
#endif
  // Start TFT and fill black
  if (!arcada.arcadaBegin()) {
    Serial.print("Failed to begin");
    while (1) delay(10);
  }
  arcada.displayBegin();
  
  // Turn on backlight
  arcada.setBacklight(255); 
  if (! arcada.createFrameBuffer(ARCADA_TFT_WIDTH, ARCADA_TFT_HEIGHT)) {
    Serial.print("Failed to allocate framebuffer");
    while (1);
  }
}



uint32_t timestamp = 0;
/**
 * @brief      Arduino main function. Runs the inferencing loop.
 */
void loop()
{
    ei_printf("Starting inferencing in 2 seconds...\n");

    delay(2000);

    ei_printf("Recording...\n");

    bool m = microphone_inference_record();
    if (!m) {
        ei_printf("ERR: Failed to record audio...\n");
        return;
    }

    ei_printf("Recording done\n");

    signal_t signal;
    signal.total_length = EI_CLASSIFIER_RAW_SAMPLE_COUNT;
    signal.get_data = &microphone_audio_signal_get_data;
    ei_impulse_result_t result = { 0 };

    EI_IMPULSE_ERROR r = run_classifier(&signal, &result, debug_nn);
    if (r != EI_IMPULSE_OK) {
        ei_printf("ERR: Failed to run classifier (%d)\n", r);
        return;
    }

    // print the predictions
    ei_printf("Predictions ");
    ei_printf("(DSP: %d ms., Classification: %d ms., Anomaly: %d ms.)",
        result.timing.dsp, result.timing.classification, result.timing.anomaly);
    ei_printf(": \n");
    for (size_t ix = 0; ix < EI_CLASSIFIER_LABEL_COUNT; ix++) {
        ei_printf("    %s: %.5f\n", result.classification[ix].label, result.classification[ix].value);
    }

    if (result.classification[0].value > result.classification[1].value) {
      sprintf(graph_title, "Boat %.2f", result.classification[0].value);
      arcada.pixels.fill(arcada.pixels.Color(0, 50, 0));
      arcada.pixels.show();
    } else {
      sprintf(graph_title, "No Boat %.2f", result.classification[1].value);
      arcada.pixels.fill(arcada.pixels.Color(50, 0, 0));
      arcada.pixels.show();
    }
    
  plotBuffer(arcada.getCanvas(), inference.buffer, inference.n_samples, graph_title);
  arcada.blitFrameBuffer(0, 0, false, true);


}




void plotBuffer(GFXcanvas16 *_canvas, int16_t *buffer, uint32_t buf_len, char *title) {
  _canvas->fillScreen(BACKGROUND_COLOR);
  _canvas->drawLine(PLOT_LEFTBUFFER-1, PLOT_TOPBUFFER, 
                    PLOT_LEFTBUFFER-1, PLOT_H+PLOT_TOPBUFFER, BORDER_COLOR);
  _canvas->drawLine(PLOT_LEFTBUFFER-1, PLOT_TOPBUFFER+PLOT_H+1, 
                    ARCADA_TFT_WIDTH, PLOT_TOPBUFFER+PLOT_H+1, BORDER_COLOR);
  _canvas->setTextSize(2);
  _canvas->setTextColor(TITLE_COLOR);
  uint16_t title_len = strlen(title) * 12;
  _canvas->setCursor((_canvas->width()-title_len)/2, 0);
  _canvas->print(title);
  
  float minY = 0;
  float maxY = 0;

 
  maxY = minY = buffer[0];
  
  for (int i=0; i< buf_len; i++) {
    minY = min(minY, buffer[i]);
    maxY = max(maxY, buffer[i]);
  }
  //Serial.printf("Data range: %f ~ %f\n", minY, maxY);

  float MIN_DELTA = 10.0;
  if (maxY - minY < MIN_DELTA) {
     float mid = (maxY + minY) / 2;
     maxY = mid + MIN_DELTA / 2;
     minY = mid - MIN_DELTA / 2;
  } else {
    float extra = (maxY - minY) / 10;
    maxY += extra;
    minY -= extra;
  }
  //Serial.printf("Y range: %f ~ %f\n", minY, maxY);

  printTicks(_canvas, 5, minY, maxY);

  int16_t last_y = 0, last_x = 0;
  uint32_t buf_step = 0;
  int16_t steps = floor(buf_len / PLOT_W);
  for (int i=0; i<PLOT_W; i++) {

    int16_t y = map(buffer[buf_step], minY, maxY, PLOT_TOPBUFFER+PLOT_H, PLOT_TOPBUFFER);
        buf_step = buf_step + steps;
    //Serial.printf("%0.1f -> %d, ", cbuffer[i], y);
    int16_t x = PLOT_LEFTBUFFER+i;
    //y = TFT_H - y + PLOT_BOTTOMBUFFER - PLOT_TOPBUFFER;
    if (i == 0) {
      last_y = y;
      last_x = x;
    }
    _canvas->drawLine(last_x, last_y, x, y, PLOT_COLOR_1);
    last_x = x;
    last_y = y;
  }

}


void printTicks(GFXcanvas16 *_canvas, uint8_t ticks, float minY, float maxY) {
  _canvas->setTextSize(1);
  _canvas->setTextColor(TICKTEXT_COLOR);
  // Draw ticks
  for (int t=0; t<ticks; t++) {
    float v = map(t, 0, ticks-1, minY, maxY);
    uint16_t y = map(t, 0, ticks-1, ARCADA_TFT_HEIGHT - PLOT_BOTTOMBUFFER - 4, PLOT_TOPBUFFER);
    printLabel(_canvas, 0, y, v);
    uint16_t line_y = map(t, 0, ticks-1, ARCADA_TFT_HEIGHT - PLOT_BOTTOMBUFFER, PLOT_TOPBUFFER);
    _canvas->drawLine(PLOT_LEFTBUFFER, line_y, ARCADA_TFT_WIDTH, line_y, TICKLINE_COLOR);
  }
}

void printLabel(GFXcanvas16 *_canvas, uint16_t x, uint16_t y, float val) {
  char label[20];
  if (abs(val) < 1) {
    snprintf(label, 19, "%0.2f", val);
  } else if (abs(val) < 10) {
    snprintf(label, 19, "%0.1f", val);
  } else {
    snprintf(label, 19, "%d", (int)val);
  }
  
  _canvas->setCursor(PLOT_LEFTBUFFER-strlen(label)*6-5, y);
  _canvas->print(label);
}





/**
 * @brief      Printf function uses vsnprintf and output using Arduino Serial
 *
 * @param[in]  format     Variable argument list
 */
void ei_printf(const char *format, ...) {
    static char print_buf[1024] = { 0 };

    va_list args;
    va_start(args, format);
    int r = vsnprintf(print_buf, sizeof(print_buf), format, args);
    va_end(args);

    if (r > 0) {
        Serial.write(print_buf);
    }
}


void TIMER_CALLBACK() {

  int32_t sample = 0;

    if (inference.buf_ready == 0) {
              sample = analogRead(USE_EXTERNAL_MIC);
              sample -= 2047; // 12 bit audio unsigned  0-4095 to signed -2048-~2047
                #if defined(AUDIO_OUT)
                  analogWrite(AUDIO_OUT, (sample+2048)); 
                #endif
              //Serial.println(sample);
            inference.buffer[inference.buf_count++] = (int16_t) sample;

            if(inference.buf_count >= inference.n_samples) {
                inference.buf_count = 0;
                inference.buf_ready = 1;
            }
        
    }
}





/**
 * @brief      Init inferencing struct and setup/start PDM
 *
 * @param[in]  n_samples  The n samples
 *
 * @return     { description_of_the_return_value }
 */
static bool microphone_inference_start(uint32_t n_samples)
{
    inference.buffer = (int16_t *)malloc(n_samples * sizeof(int16_t));

    if(inference.buffer == NULL) {
        return false;
    }

    inference.buf_count  = 0;
    inference.n_samples  = n_samples;
    inference.buf_ready  = 0;

    // configure the data receive callback
    //PDM.onReceive(&pdm_data_ready_inference_callback);



    return true;
}

/**
 * @brief      Wait on new data
 *
 * @return     True when finished
 */
static bool microphone_inference_record(void)
{
    inference.buf_ready = 0;
    inference.buf_count = 0;

    while(inference.buf_ready == 0) {
        delay(10);
    }

    return true;
}

/**
 * Get raw audio signal data
 */
static int microphone_audio_signal_get_data(size_t offset, size_t length, float *out_ptr)
{
    numpy::int16_to_float(&inference.buffer[offset], out_ptr, length);

    return 0;
}

/**
 * @brief      Stop PDM and release buffers
 */
static void microphone_inference_end(void)
{
    free(inference.buffer);
}

#if !defined(EI_CLASSIFIER_SENSOR) || EI_CLASSIFIER_SENSOR != EI_CLASSIFIER_SENSOR_MICROPHONE
#error "Invalid model for current sensor."
#endif

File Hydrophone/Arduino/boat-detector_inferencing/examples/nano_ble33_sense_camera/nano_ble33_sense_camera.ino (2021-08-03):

/* Edge Impulse Arduino examples
 * Copyright (c) 2021 EdgeImpulse Inc.
 *
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
 * THE SOFTWARE IS PROVIDED "AS IS", WITHOUT WARRANTY OF ANY KIND, EXPRESS OR
 * IMPLIED, INCLUDING BUT NOT LIMITED TO THE WARRANTIES OF MERCHANTABILITY,
 * FITNESS FOR A PARTICULAR PURPOSE AND NONINFRINGEMENT. IN NO EVENT SHALL THE
 * AUTHORS OR COPYRIGHT HOLDERS BE LIABLE FOR ANY CLAIM, DAMAGES OR OTHER
 * LIABILITY, WHETHER IN AN ACTION OF CONTRACT, TORT OR OTHERWISE, ARISING FROM,
 * OUT OF OR IN CONNECTION WITH THE SOFTWARE OR THE USE OR OTHER DEALINGS IN THE
 * SOFTWARE.
 */

/* Includes ---------------------------------------------------------------- */
#include <boat-detector_inferencing.h>
#include <Arduino_OV767X.h>

class EiCamera : public OV767X {
    public:
        int begin(int resolution, int format, int fps);
        void readFrame(void* buffer);

    private:
        int vsyncPin;
        int hrefPin;
        int pclkPin;
        int xclkPin;

        volatile uint32_t* vsyncPort;
        uint32_t vsyncMask;
        volatile uint32_t* hrefPort;
        uint32_t hrefMask;
        volatile uint32_t* pclkPort;
        uint32_t pclkMask;

        uint16_t width;
        uint16_t height;
        uint8_t bytes_per_pixel;
        uint16_t bytes_per_row;
        uint8_t buf_rows;
        uint16_t buf_size;
        uint8_t *raw_buf;
        uint8_t *intrp_buf;

        void readRow();
        void interpolateRow(int offset, uint8_t* in, uint8_t* out);
};


typedef struct {
	size_t width;
	size_t height;
} ei_device_resize_resolutions_t;

/* Constant variables ------------------------------------------------------- */
#define EI_CAMERA_RAW_FRAME_BUFFER_COLS     160
#define EI_CAMERA_RAW_FRAME_BUFFER_ROWS     120

#define DWORD_ALIGN_PTR(a)   ((a & 0x3) ?(((uintptr_t)a + 0x4) & ~(uintptr_t)0x3) : a)

/* Private variables ------------------------------------------------------- */
static EiCamera Cam;
static bool is_initialised = false;
static bool has_camera = false;

/*
** @brief points to the output of the capture
*/
static uint8_t *ei_camera_capture_out = NULL;

static bool debug_nn = false; // Set this to true to see e.g. features generated from the raw signal

void resizeImage(int srcWidth, int srcHeight, uint8_t *srcImage, int dstWidth, int dstHeight, uint8_t *dstImage, int iBpp);
void cropImage(int srcWidth, int srcHeight, uint8_t *srcImage, int startX, int startY, int dstWidth, int dstHeight, uint8_t *dstImage, int iBpp);

/**
* @brief      Arduino setup function
*/
void setup()
{
    // put your setup code here, to run once:
    Serial.begin(115200);
    Serial.println("Edge Impulse Inferencing Demo");

    // summary of inferencing settings (from model_metadata.h)
    ei_printf("Inferencing settings:\n");
    ei_printf("\tImage resolution: %dx%d\n", EI_CLASSIFIER_INPUT_WIDTH, EI_CLASSIFIER_INPUT_HEIGHT);
    ei_printf("\tFrame size: %d\n", EI_CLASSIFIER_DSP_INPUT_FRAME_SIZE);
    ei_printf("\tNo. of classes: %d\n", sizeof(ei_classifier_inferencing_categories) / sizeof(ei_classifier_inferencing_categories[0]));

    if (ei_camera_init() == false) {
        ei_printf("Failed to initialize camera\r\n");
        return;
    }
    else {
        ei_printf("Camera initialized\r\n");
    }
}

/**
 * @brief      Determine whether to resize and to which dimension
 *
 * @param[in]  out_width     width of output image
 * @param[in]  out_height    height of output image
 * @param[out] resize_col_sz       pointer to frame buffer's column/width value
 * @param[out] resize_row_sz       pointer to frame buffer's rows/height value
 * @param[out] do_resize     returns whether to resize (or not)
 *
 */
static int calculate_resize_dimensions(uint32_t out_width, uint32_t out_height, uint32_t *resize_col_sz, uint32_t *resize_row_sz, bool *do_resize)
{
    size_t list_size = 2;
    ei_device_resize_resolutions_t list[list_size] = { {32,32}, {96,96} };

    // (default) conditions
    *resize_col_sz = EI_CAMERA_RAW_FRAME_BUFFER_COLS;
    *resize_row_sz = EI_CAMERA_RAW_FRAME_BUFFER_ROWS;
    *do_resize = false;

    for (size_t ix = 0; ix < list_size; ix++) {
        if ((out_width <= list[ix].width) && (out_height <= list[ix].height)) {
            *resize_col_sz = list[ix].width;
            *resize_row_sz = list[ix].height;
            *do_resize = true;
            break;
        }
    }

    return 0;
}

/**
 * @brief   Setup image sensor & start streaming
 *
 * @retval  false if initialisation failed
 */
bool ei_camera_init(void) {
    if (is_initialised) return true;
    
    if (!Cam.begin(QQVGA, RGB565, 1)) { // VGA downsampled to QQVGA (EiCamera)
        ei_printf("ERR: Failed to initialize camera\r\n");
        return false;
    }
    is_initialised = true;
    has_camera = true;

    return true;
}

/**
 * @brief      Stop streaming of sensor data
 */
void ei_camera_deinit(void) {
    if (is_initialised) {
        Cam.end();
        is_initialised = false;
    }
}
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

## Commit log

2022-02-01 power and pijuice don't need network access
2022-02-04 add Particle Tracker Buoy
    [4in PVC Particle Tracker Buoy - 3D Printed Electronics Payload Chassis Center Panel^4in PVC Particle Tracker Buoy-1.STL, 4in PVC Particle Tracker Buoy - 3D Pri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]
2022-02-04 missing sensors; rename
2022-02-04 add case chassis parts and info
    [phat-stack-mount.STL, se56-chassis.STL]
2022-02-05 configure power
2022-02-06 fix timestamps, add power and uptime to status
2022-02-06 forgot battery_status
2022-02-08 only send low battery webhook once
2022-02-10 fix power checks
2022-02-14 use a class and add tests for power
2022-02-14 override timers for tests
2022-02-14 add check in case external script fails
2022-02-16 add power coverage.
2022-02-20 switch to only uploading once a day
2022-02-24 add CAD animation
2022-03-21 build for different arm versions
2022-04-20 Add collection and sample JSON documentation.
2022-04-22 Add a utility to probe audio files using ffprobe and to collect the results
2022-04-29 CAD render updates
2022-04-29 updates to docs
    [config.txt]
2022-05-10 Pin pandas version
2022-05-10 update particle tracker cad renders
2022-05-16 pibuoy cad render updates
2022-05-20 updated pibuoy cad animation
2022-05-23 Filter clips by maximum distance from hydrophone
2022-06-22 Update plots for positions and track for v3-mk1-2
2022-06-29 remove debug print statement
2022-07-18 Update to particle tracker buoy BOM
2022-08-10 Uploading SE56 Mounting Brackets
    [SE56Mount-Left.stl, SE56Mount-Right.stl]
2022-09-20 update chassis stl
    [se56-chassis.STL]
2022-10-06 updated flowchart
2022-10-17 pytype 2022.10.13 gets confused by the global reference t as a Telem instance, and also t as a temperature reading.
2022-10-17 pytype 2022.10.13 hangs unless sensor_data has been defined at class initialization time.
2022-10-17 Upgrade pytype to 2022.10.13, workaround another pytype hang, initializing sensor data from a loop rather than static reference, and ensure timeout for pytype.
2022-12-09 Clean up from Raspberry Pi buoy transfer
    [SE56Mount-Left.stl, SE56Mount-Right.stl, config.txt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]
2022-12-09 remove arduino-test action

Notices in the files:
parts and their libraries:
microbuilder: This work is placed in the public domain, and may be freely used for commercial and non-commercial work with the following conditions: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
